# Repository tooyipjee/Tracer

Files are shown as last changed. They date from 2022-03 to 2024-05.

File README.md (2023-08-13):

# Tracer - A Wearable for Things!

 
 The Tracer is an open-source ESP32-based Inertial Measurement Unit tracker that allows you to track the motion and orientation of objects and stream the data to your smartphone or computer.
 
 This repository contains the following content;
 - Schematic
 - Example code to get started with streaming data over Bluetooth (BLE) to your smartphone via [Phyphox](https://github.com/phyphox)
 - 3D Visualisation via Processing
 
 ## What is it
Have you ever wanted to just stick an IMU on a thing to trace its pose and motion?
Tracer provides reliable high-performance and cost efficient tracking of objects for a variety of applications. Tracer can be easily mounted using a high quality velcro strap, allowing it to be fastened on the frame of a bicycle for lean and cadence tracking or even the neck of a tennis racquet to count number of strokes and potentially differentiate between top spin and slice. Let you imagination run wild!

Leveraging on existing open-source projects the Tracer fully supports integration with Phyphox, and can be programmed using Micropython, and Arduino. Power users can also use the [ESP-IDF](https://github.com/espressif/esp-idf) tool for maximum customisation. 

Key Features;
- Leverage the [LSM6DSL](https://www.st.com/en/mems-and-sensors/lsm6dsl.html) to track your objects in real-time.
- Easy mounting using high quality velcro straps that allow the unit to be mounted on a wide variety of objects from your bicycle to track lean angles to an tennis racquet for pose insights.
- On-board Li-ion battery charging using the TP4065.
- Battery Life - 3 hours of continuous streaming over BLE at 10Hz.
- 15m BLE range (unobstructed) - tested on a tennis court

## Use cases

The example code used to test this design involves close integration with the [Madgwick Filter](https://ahrs.readthedocs.io/en/latest/filters/madgwick.html). Using that filter to perform sensor fusion and generate an estimate for heading, roll and pitch, the data can then be relayed to a smartphone or PC for post processing. See below for two example

### Real-time 3D Visualisation
<p align="center">
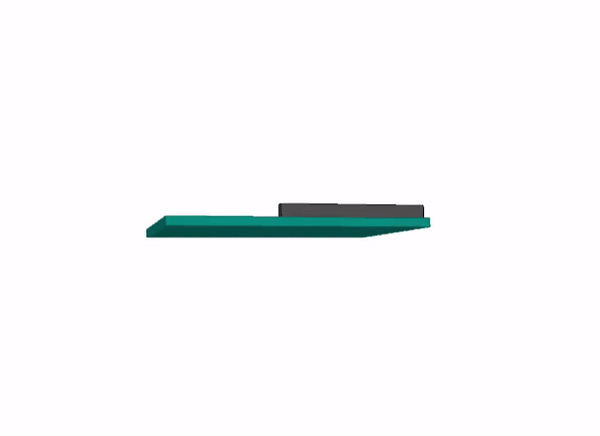
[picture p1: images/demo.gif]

</p>
This 3D visualisation is by streaming data over UART to a simple script that was written on [Processing](https://github.com/processing).

### Stream real-time data to phyphox 
<p align="center">

</p>
The real-time plots from the IMU is streamed over BLE to the phone. Data can later be exported over CSV for further analysis if required. Phyphox is also capable of performing DSP which should offload any energy intensive computation from the ESP32.

## Specification
* Microcontroller | [ESP32-PICO-D4](https://www.espressif.com/en/producttype/esp32-pico-d4)
    * WiFi | 802.11b/g/n
    * Bluetooth | BLE 4.2
    * FLASH | 4MB
    * Programming | USB over UART (CP2104)
* Inertial Measurement Unit (IMU) | [LSM6DSLTR](https://www.st.com/en/mems-and-sensors/lsm6dsl.html)
    * Accelerometer | ±2/±4/±8/±16 g at 1.6 Hz to 6.7KHz
    * Gyroscope | ±125/±250/±500/±1000/±2000 dps at 12.5 Hz to 6.7 KHz
* Time-of-Flight (TOF) | [VL53L0X](https://www.st.com/en/imaging-and-photonics-solutions/vl53l0x.html)
    * Range | Up to 2m
    * 1D Gesture Recognition
* Li-ion Battery Management | TP4065
* Power | 700mA 3.3V LDO
* Mechanical
    * Weight | 20g, including velcro strap
    * Dimensions | 4.2 x 3.6 cm
    * Mounting Options | Velcro Strap or 3x M.2.Screws

## License

MIT License

Copyright (c) 2022 tooyipjee

Permission is hereby granted, free of charge, to any person obtaining a copy
of this software and associated documentation files (the "Software"), to deal
in the Software without restriction, including without limitation the rights
to use, copy, modify, merge, publish, distribute, sublicense, and/or sell
copies of the Software, and to permit persons to whom the Software is
furnished to do so, subject to the following conditions:

The above copyright notice and this permission notice shall be included in all
copies or substantial portions of the Software.

THE SOFTWARE IS PROVIDED "AS IS", WITHOUT WARRANTY OF ANY KIND, EXPRESS OR
IMPLIED, INCLUDING BUT NOT LIMITED TO THE WARRANTIES OF MERCHANTABILITY,
FITNESS FOR A PARTICULAR PURPOSE AND NONINFRINGEMENT. IN NO EVENT SHALL THE
AUTHORS OR COPYRIGHT HOLDERS BE LIABLE FOR ANY CLAIM, DAMAGES OR OTHER
LIABILITY, WHETHER IN AN ACTION OF CONTRACT, TORT OR OTHERWISE, ARISING FROM,
OUT OF OR IN CONNECTION WITH THE SOFTWARE OR THE USE OR OTHER DEALINGS IN THE
SOFTWARE.

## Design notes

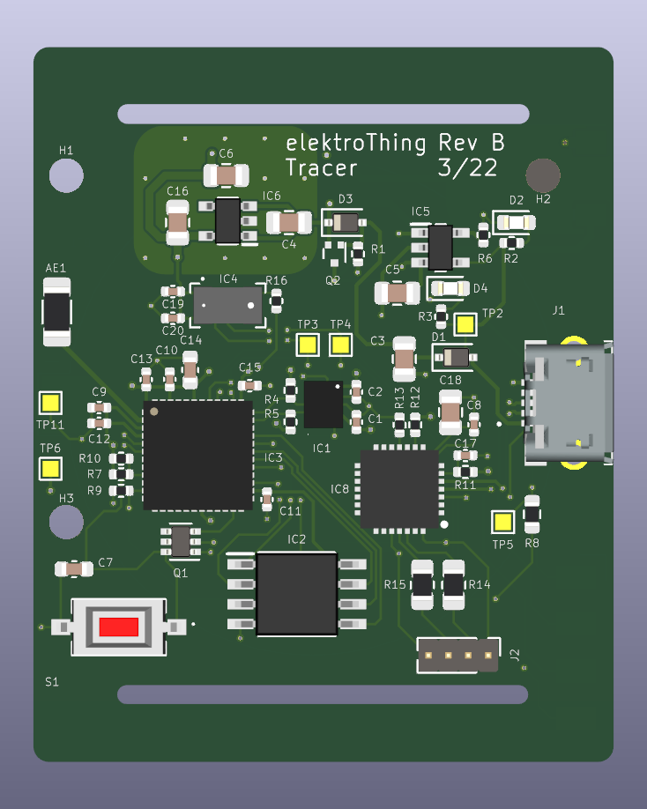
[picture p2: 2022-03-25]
images/pinout/hardware.png

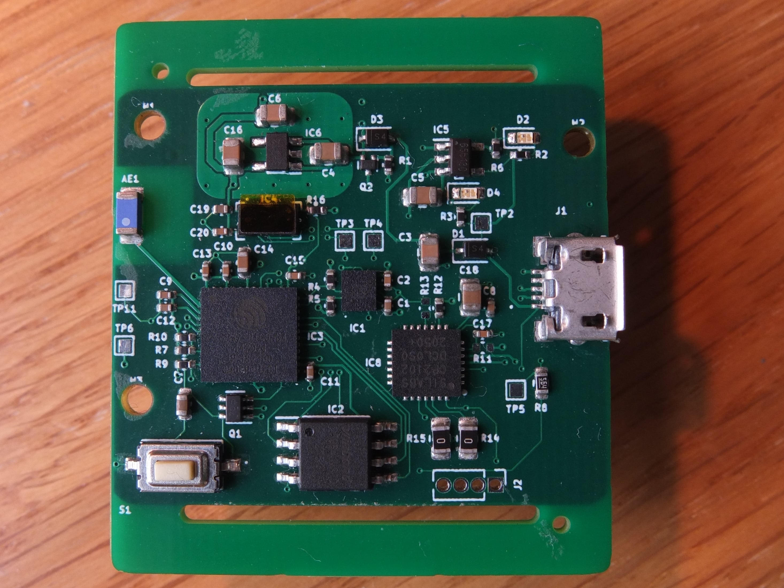
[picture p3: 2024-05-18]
images/revB/DSCF9603-min.JPG

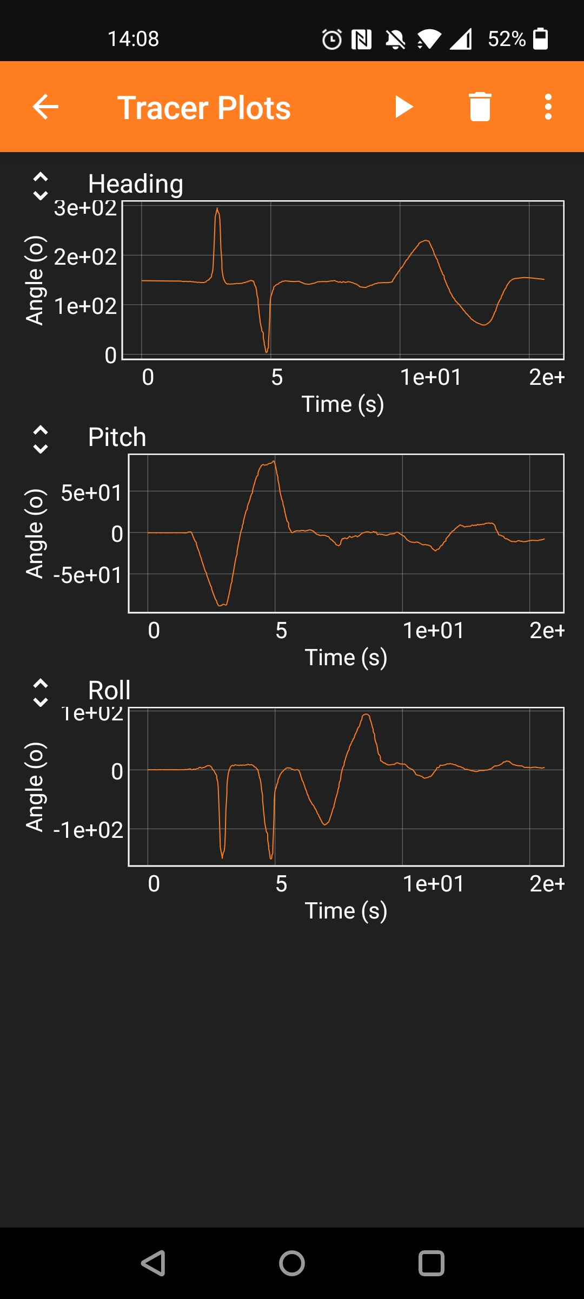
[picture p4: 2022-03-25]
images/phyphox.jpg

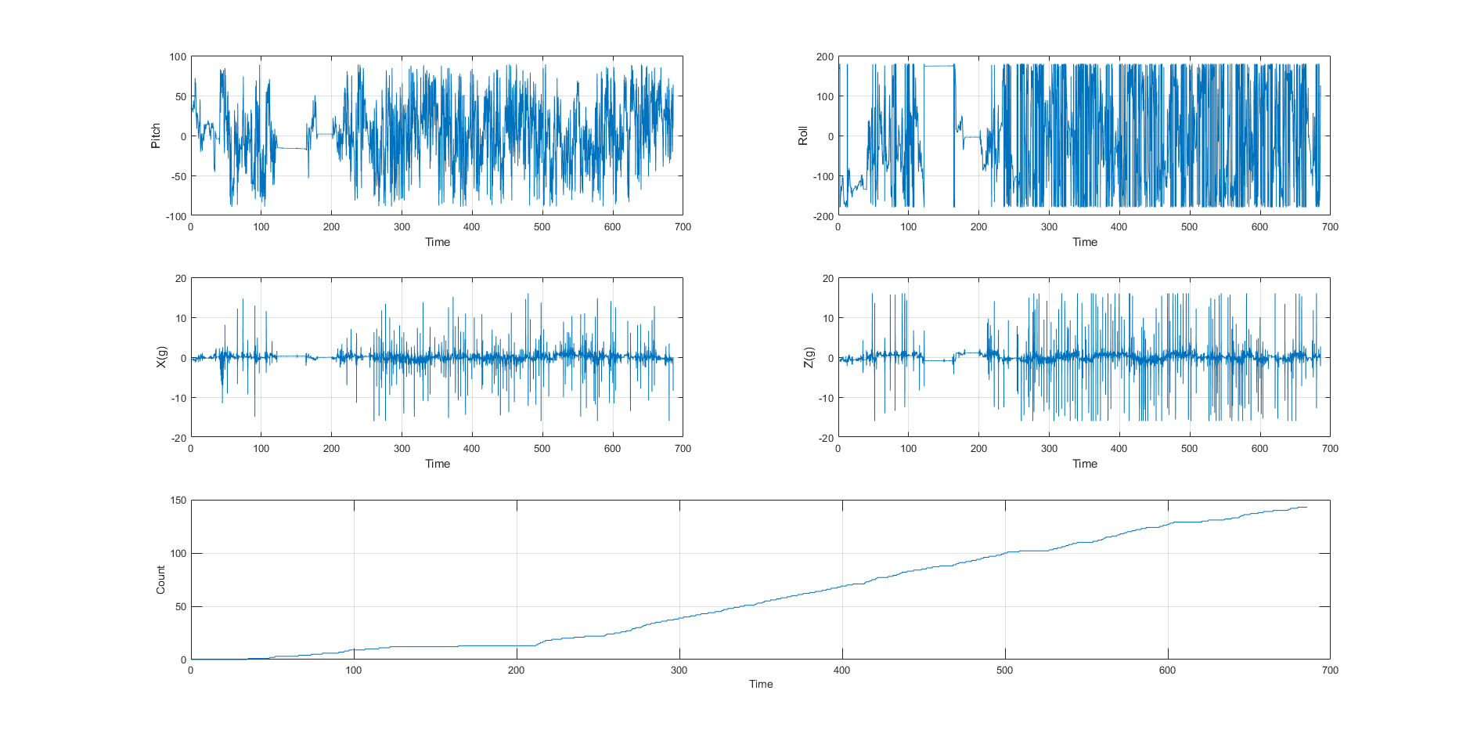
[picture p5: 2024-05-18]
images/tennis_18-4.png

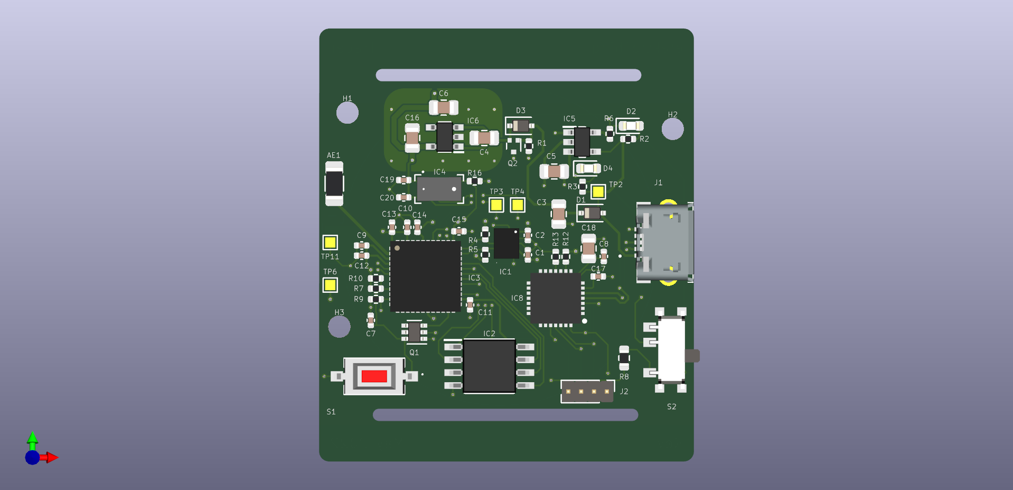
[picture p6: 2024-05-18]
images/Tracer.png

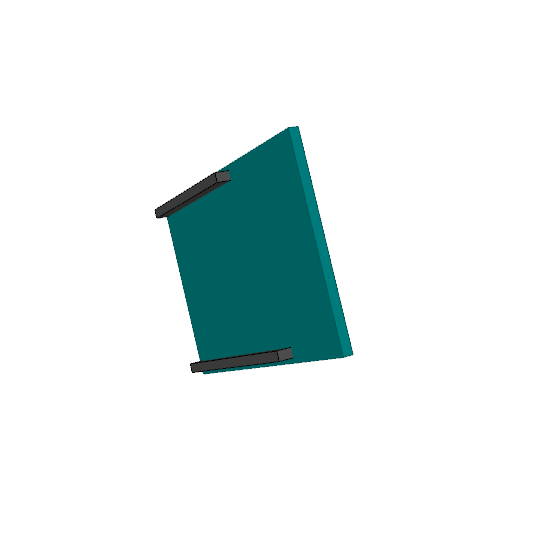
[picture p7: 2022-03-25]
images/visual.png

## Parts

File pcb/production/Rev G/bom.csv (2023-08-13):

Designator | Footprint | Quantity | Value | LCSC Part #
BT1 | BS-24-B4AK014 | 1 | CR2450 | C964813
C1, C7 | 0402 | 2 | 1u | C52923
C10 | 1206 | 1 | 4.7u | C29823
C11, C12, C13, C14, C2, C5, C6 | 0402 | 7 | 100n | C307331
C15 | 0402 | 1 | 10u_0402 | C315248
C3, C4, C8, C9 | 0805 | 4 | 10u | C15850
D2, D3, D4, D5 | 0603 | 4 | Green_0603 | C72043
D6 | B5819WSL | 1 | B5819W.SL | C8598
H1, H2, H3 | MountingHole_2.2mm_M2_Small | 3 | MountingHole
IC1 | ESP32C3MINI1N4 | 1 | ESP32-C3-MINI-1-N4 | C2838502
IC2 | SOT95P280X130-5N | 1 | XC6227C331MR-G | C216640
IC3 | QFN50P300X300X100-17N-D | 1 | BQ24073RGTR | C15220
IC4 | LSM6DSLTR | 1 | LSM6DSLTR | C126672
IC5 | QFN50P500X500X80-29N-D | 1 | CP2102N-A02-GQFN28R | C6568
J1 | GT-USB-7010A | 1 | GT-USB-7010 | C963370
J2 | SHDRRA2W50P0X200_1X2_600X760X510P | 1 | PH-2RA | C225207
JP1, JP2 | SolderJumper-3_P1.3mm_Bridged12_Pad1.0x1.5mm_NumberLabels | 2 | SolderJumper_3_Bridged12
Q1 | SOT-363_SC-70-6 | 1 | MUN5214DW1T1G | C94403
R1, R18, R19, R3 | 0402 | 4 | 10k | C25744
R10, R11, R2 | 0402 | 3 | 2.2k | C25879
R12, R13, R14, R15, R5 | 0402 | 5 | 51k | C25794
R16 | 0603 | 1 | 560k | C23203
R17 | 0402 | 1 | 220k | C25767
R20, R4 | 0402 | 2 | 1k | C11702
R7, R9 | 0402 | 2 | 1.5k | C25867
R8 | 0402 | 1 | 100k | C25741
S1, S2 | TS1101CW | 2 | TS-1101-C-W | C318938
S3 | K31296SE1 | 1 | K3-1296S-E1 | C128955
TH1 | 0402 | 1 | 10k_NTC | C333993
TP11 | TestPoint_Pad_1.0x1.0mm | 1 | TestPoint_Alt

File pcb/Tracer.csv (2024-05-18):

Comment | Designator | Footprint | LCSC
CR2450 | BT1 | BatteryHolders:BS-24-B4AK014 | C964813
1u | C1,C7 | Capacitor_SMD:C_0402_1005Metric | C52923
4.7u | C10 | Capacitor_SMD:C_1206_3216Metric | C29823
10u_0402 | C15 | Capacitor_SMD:C_0402_1005Metric | C315248
100n | C2,C5,C6,C11,C12,C13,C14 | Capacitor_SMD:C_0402_1005Metric | C307331
10u | C3,C4,C8,C9 | Capacitor_SMD:C_0805_2012Metric | C15850
SD103AWS | D1 | Diode_SMD:D_SOD-323 | C181207
Green_0603 | D2,D3,D4,D5 | LED_SMD:LED_0603_1608Metric | C72043
MountingHole | H1,H2,H3 | personal:MountingHole_2.2mm_M2_Small
ESP32-C3-MINI-1-N4 | IC1 | ESP32C3MINI1N4 | C2838502
XC6227C331MR-G | IC2 | SOT95P280X130-5N | C216640
BQ24073RGTR | IC3 | QFN50P300X300X100-17N-D | C15220
LSM6DSLTR | IC4 | LSM6DSLTR | C126672
CP2102N-A02-GQFN28R | IC5 | QFN50P500X500X80-29N-D | C6568
GT-USB-7010 | J1 | Connectors_JT:GT-USB-7010A | C963370
MUN5214DW1T1G | Q1 | Package_TO_SOT_SMD:SOT-363_SC-70-6 | C94403
10k | R1,R3,R12,R13,R14,R15,R18,R19 | Resistor_SMD:R_0402_1005Metric | C25744
560k | R16 | Resistor_SMD:R_0603_1608Metric | C23203
220k | R17 | Resistor_SMD:R_0402_1005Metric | C25767
2.2k | R2,R10,R11 | Resistor_SMD:R_0402_1005Metric | C25879
1k | R4,R20 | Resistor_SMD:R_0402_1005Metric | C11702
47.5k | R5 | Resistor_SMD:R_0402_1005Metric | C227098
0 | R6 | Resistor_SMD:R_0805_2012Metric_Pad1.20x1.40mm_HandSolder | C17477
1.5k | R7,R9 | Resistor_SMD:R_0402_1005Metric | C25867
100k | R8 | Resistor_SMD:R_0402_1005Metric | C25741
TS-1101-C-W | S1,S2 | TS1101CW | C318938
K3-1296S-E1 | S3 | K31296SE1 | C128955
10k_NTC | TH1 | Resistor_SMD:R_0402_1005Metric | C333993
TestPoint_Alt | TP11 | TestPoint:TestPoint_Pad_1.0x1.0mm

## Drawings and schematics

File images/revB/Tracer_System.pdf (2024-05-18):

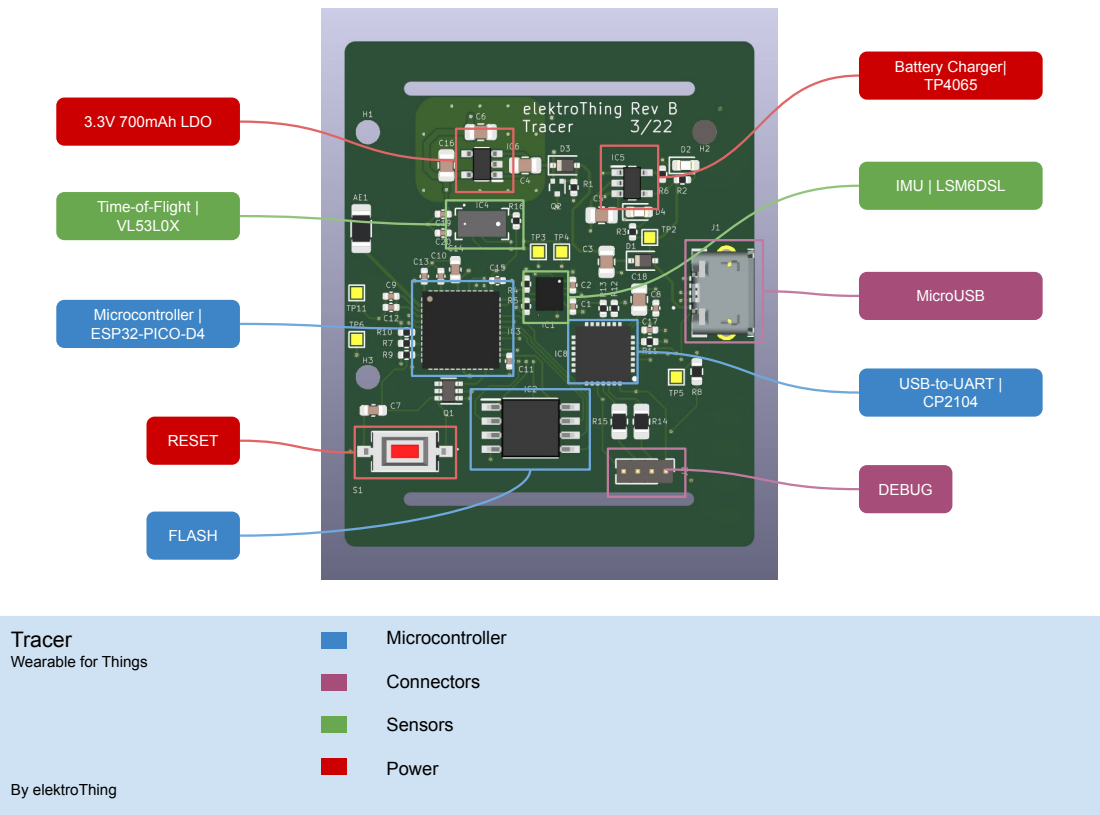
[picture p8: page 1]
By elektroThing; Microcontroller; Connectors; Sensors; Power; 3.3V 700mAh LDO; Microcontroller | ESP32-PICO-D4; RESET; IMU | LSM6DSL; MicroUSB; Battery Charger| TP4065; DEBUG; FLASH

Time-of-Flight

USB-to-UART

Tracer
Wearable for Things

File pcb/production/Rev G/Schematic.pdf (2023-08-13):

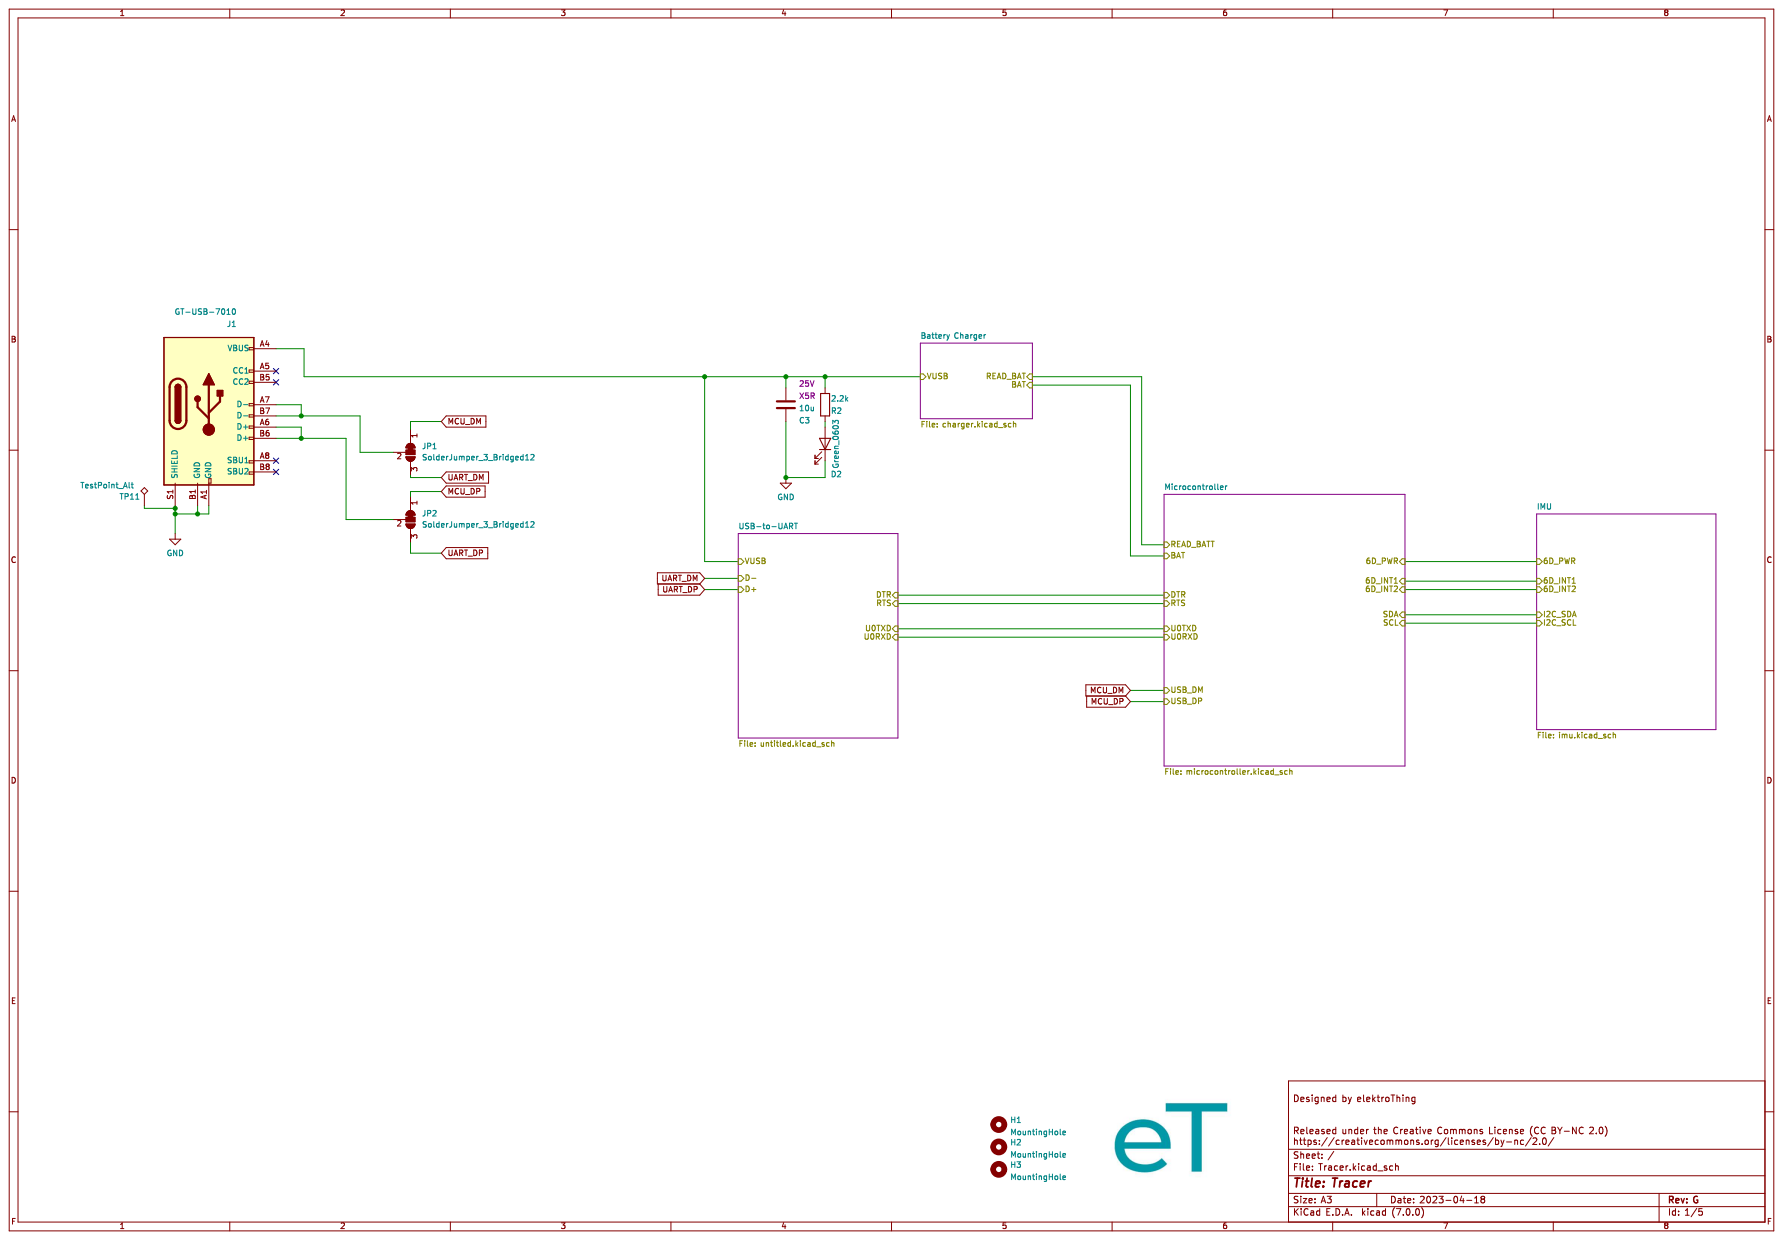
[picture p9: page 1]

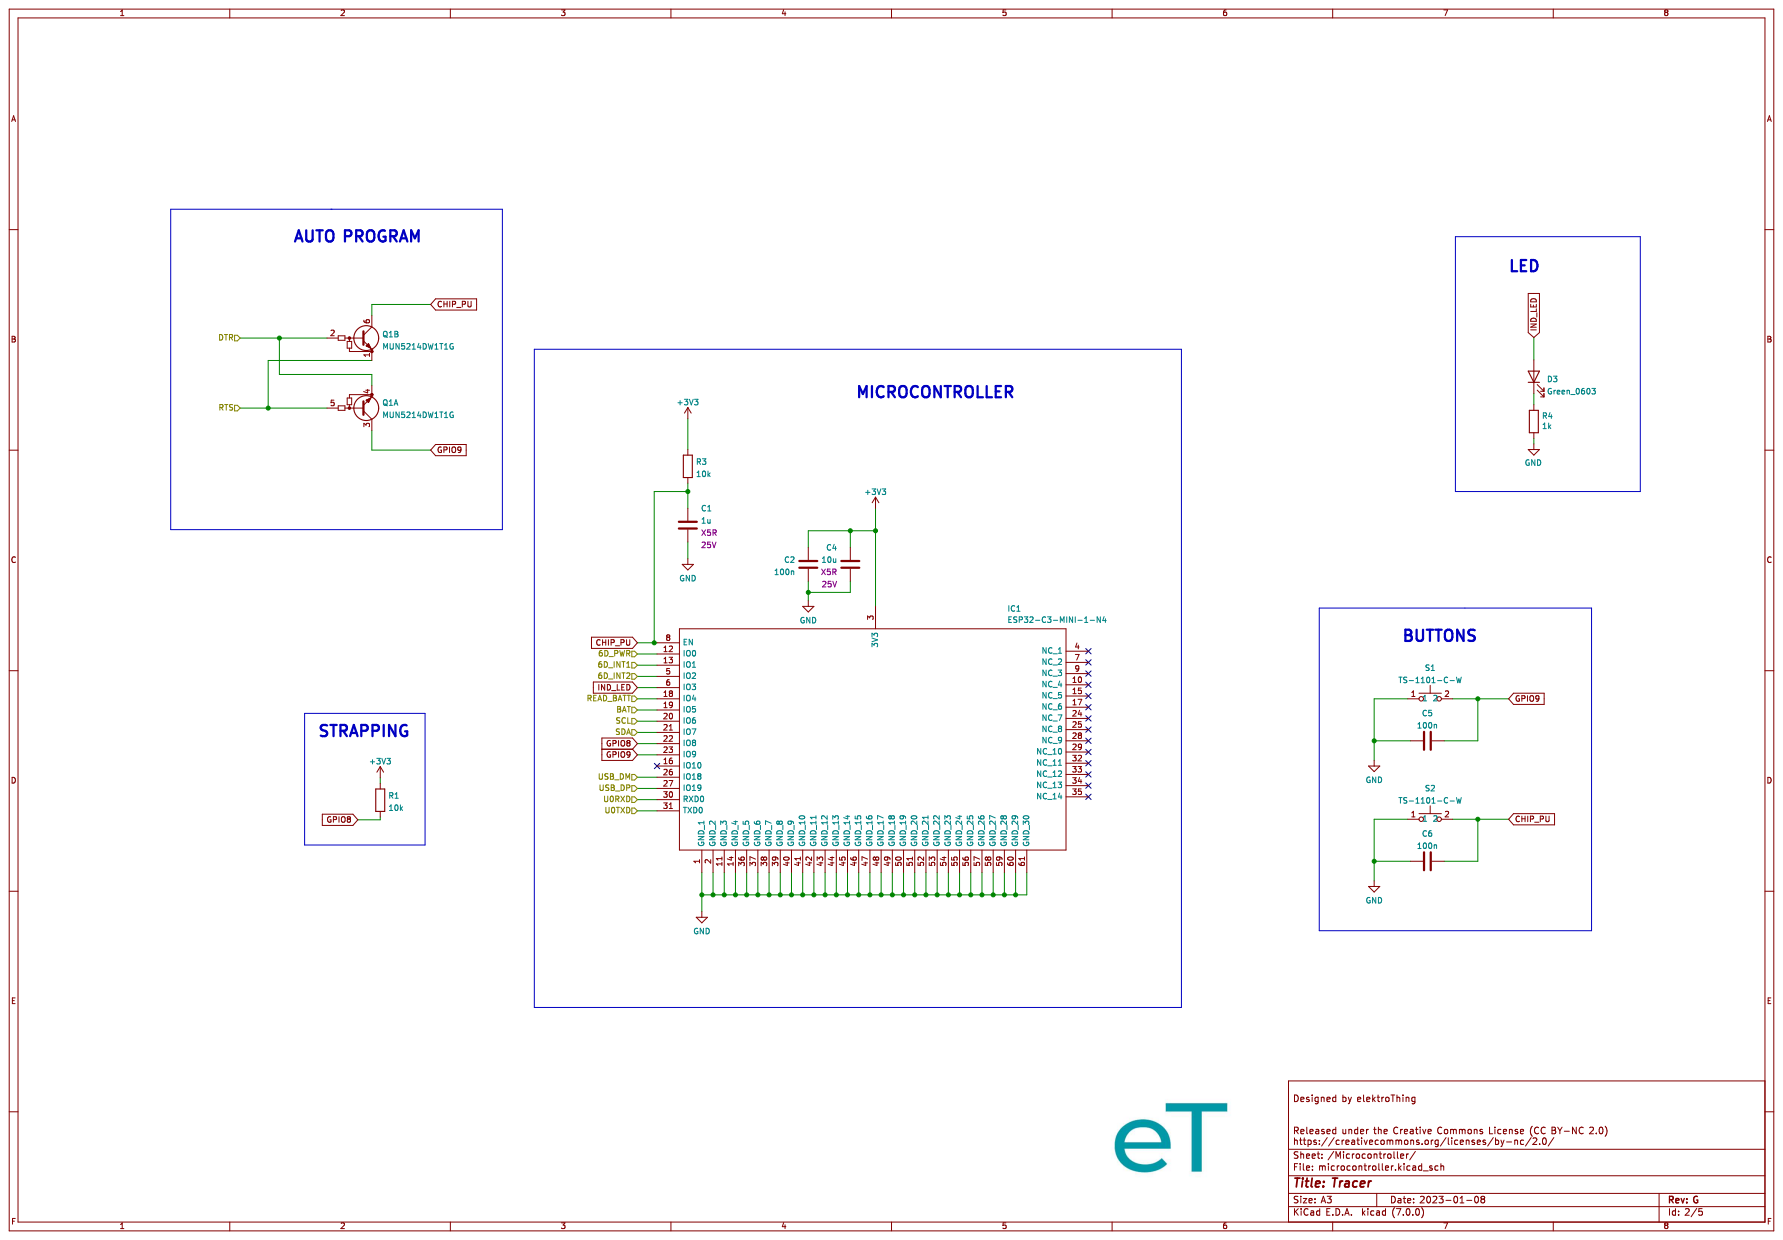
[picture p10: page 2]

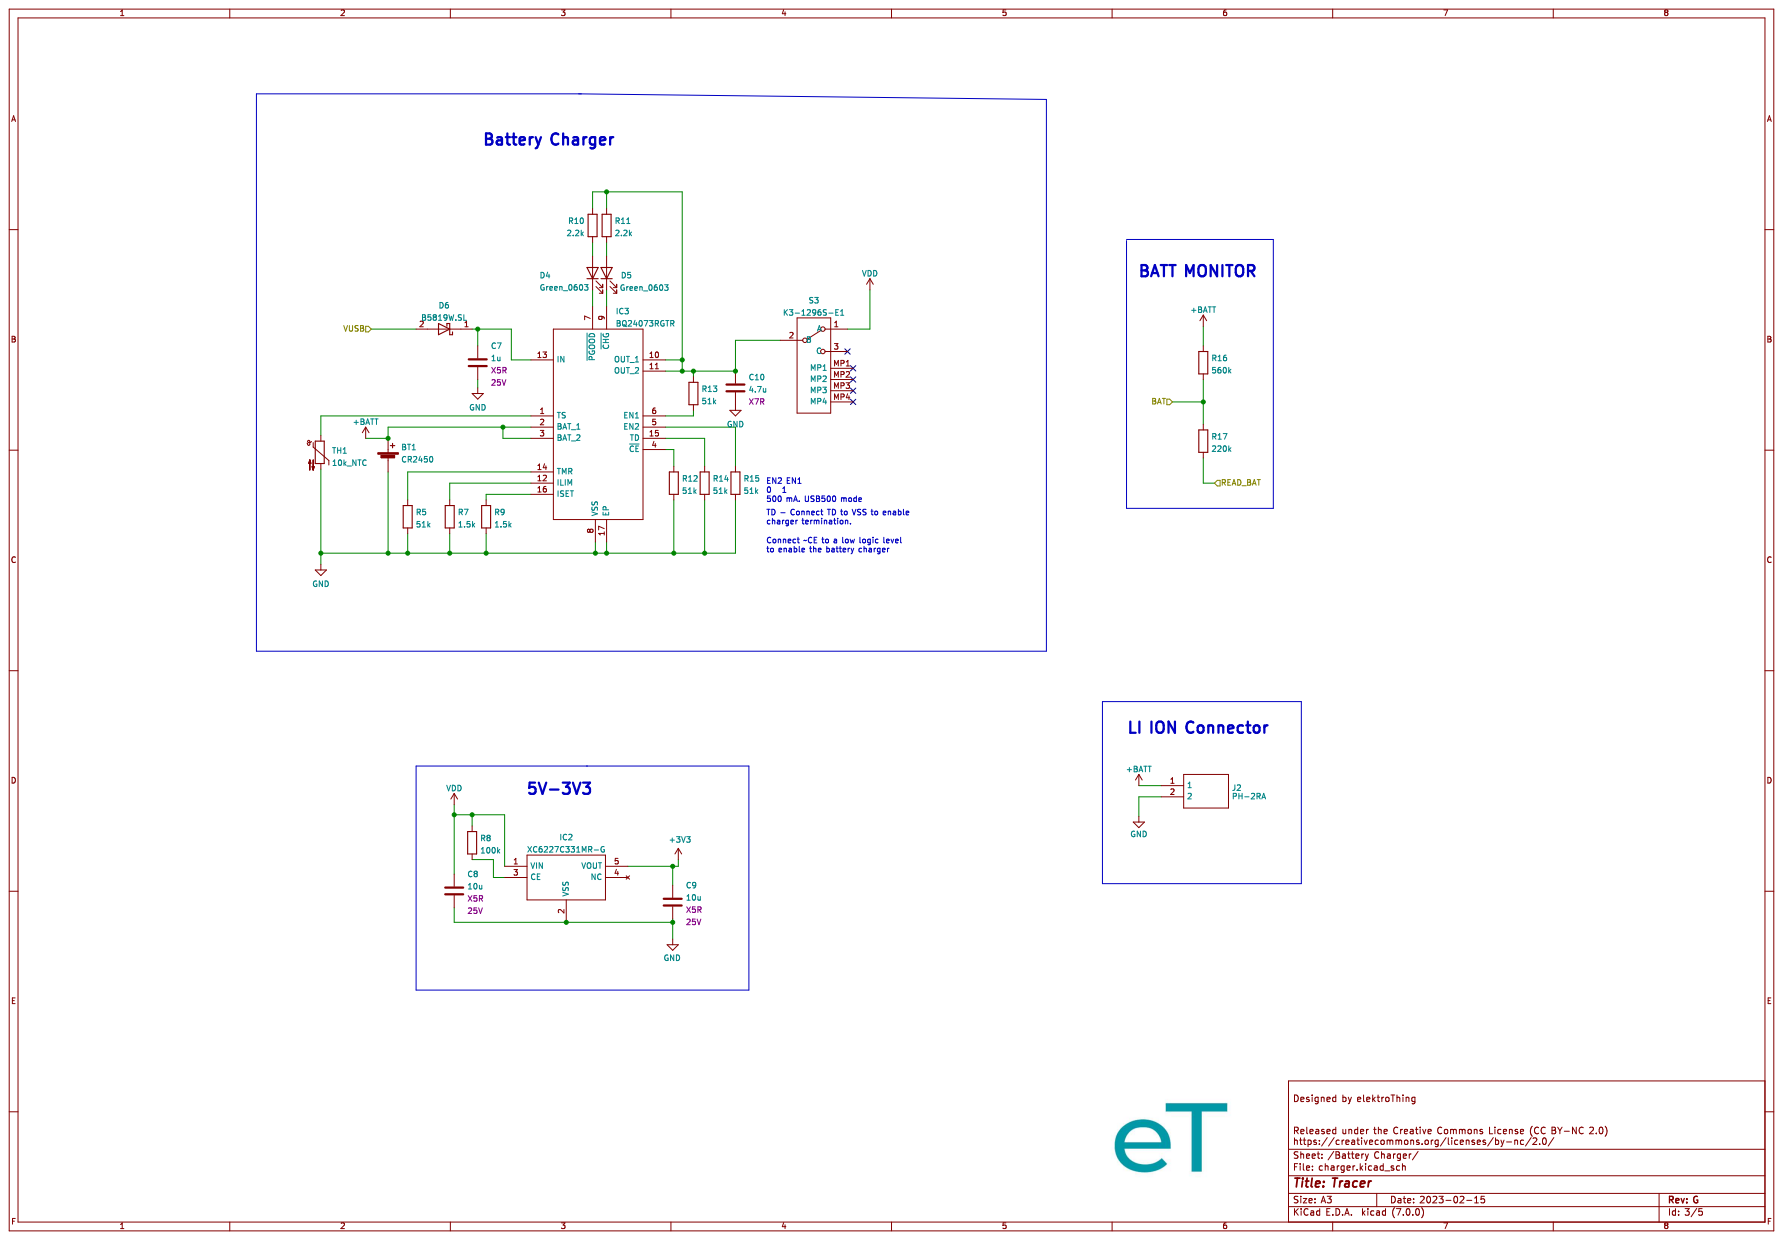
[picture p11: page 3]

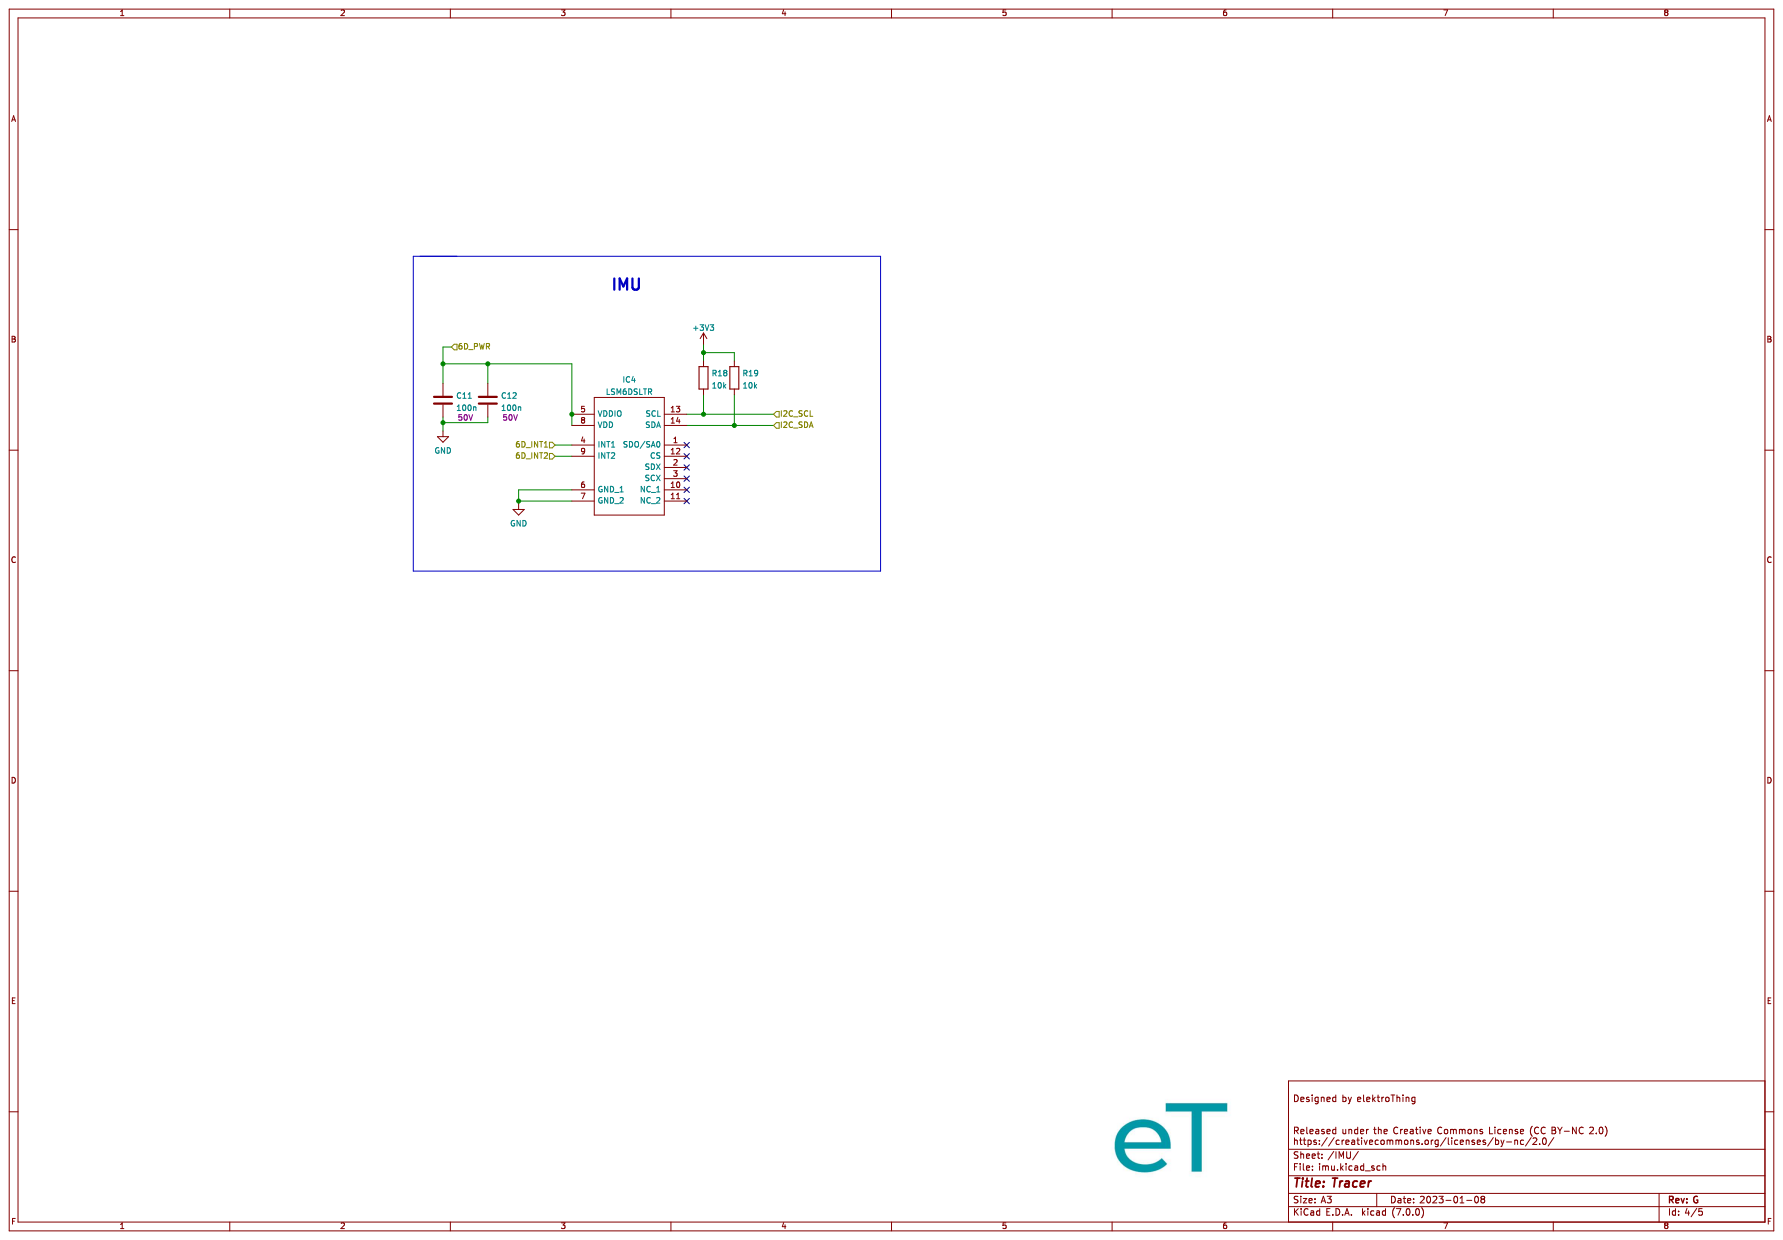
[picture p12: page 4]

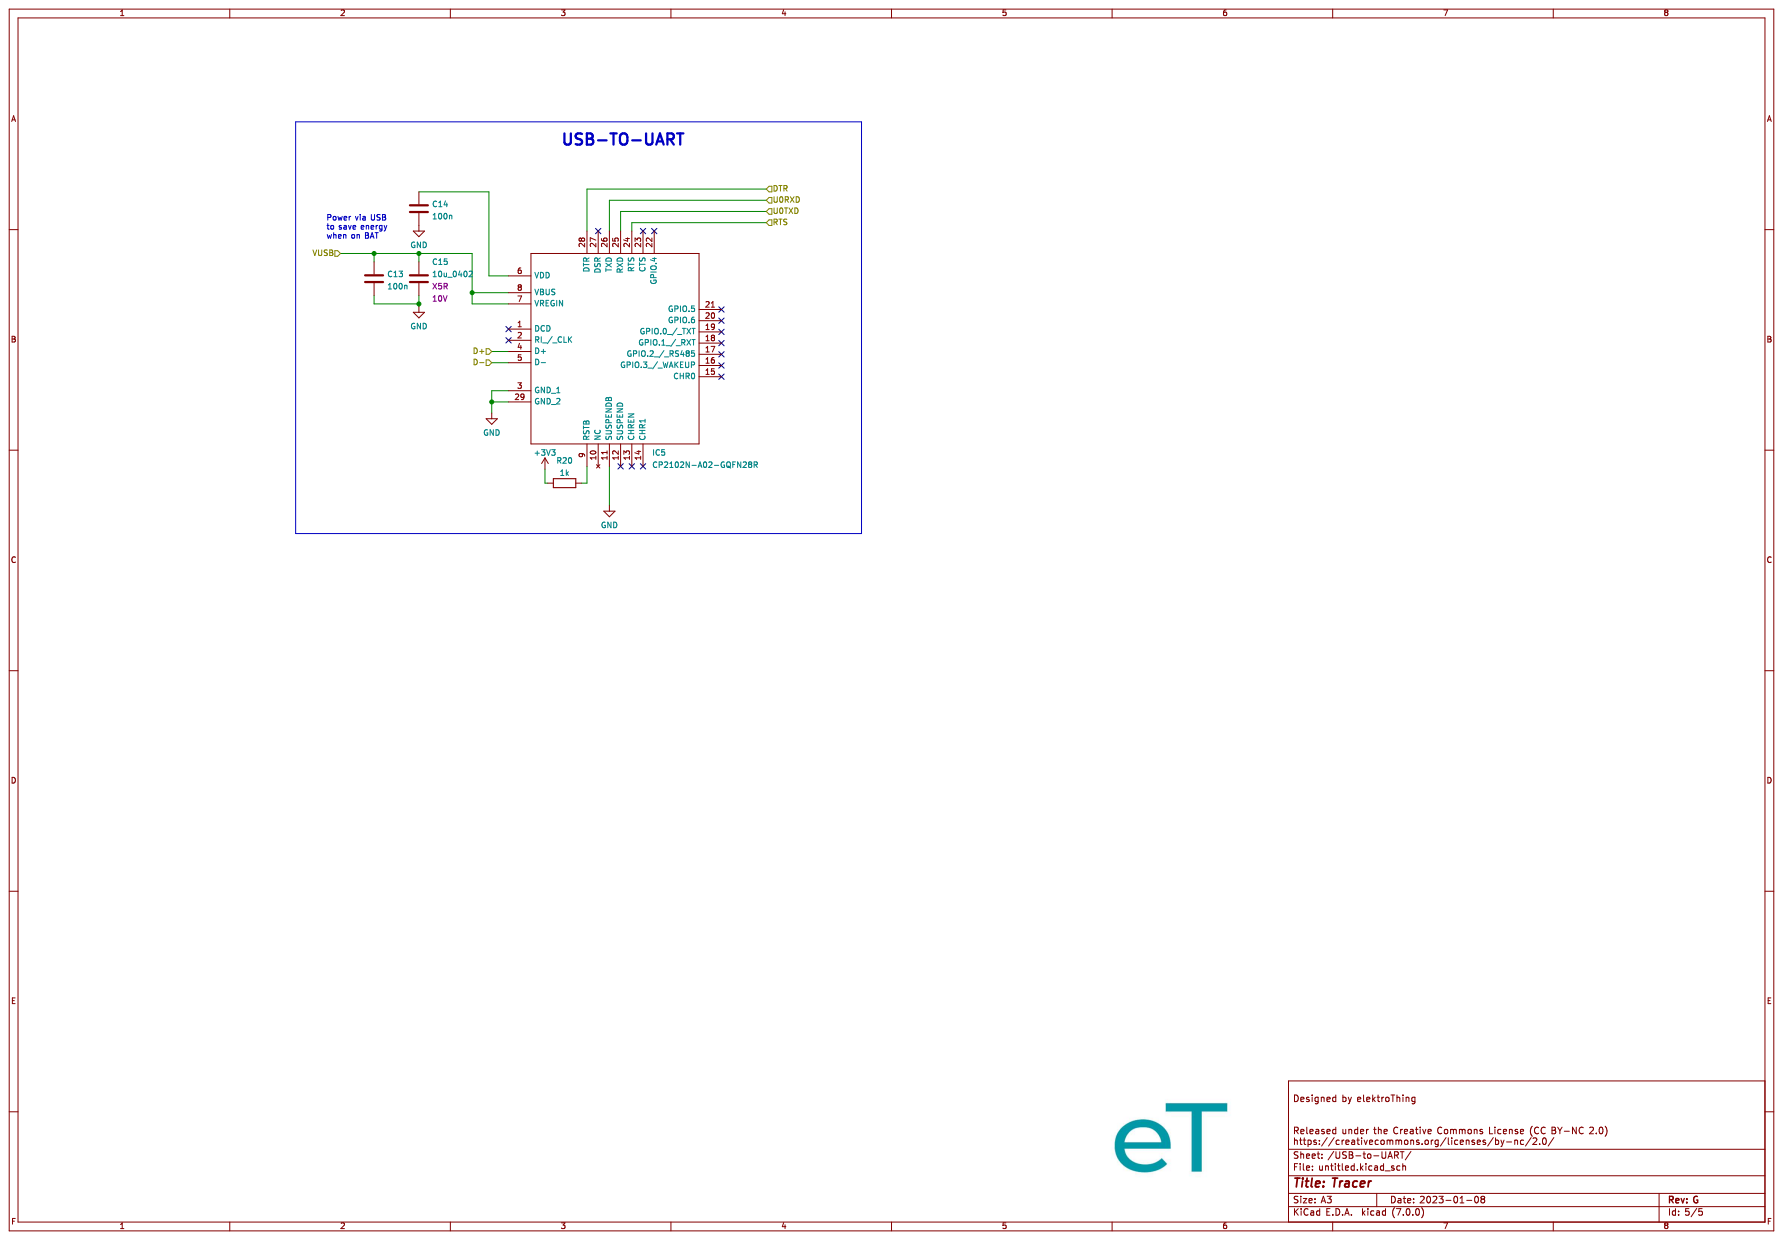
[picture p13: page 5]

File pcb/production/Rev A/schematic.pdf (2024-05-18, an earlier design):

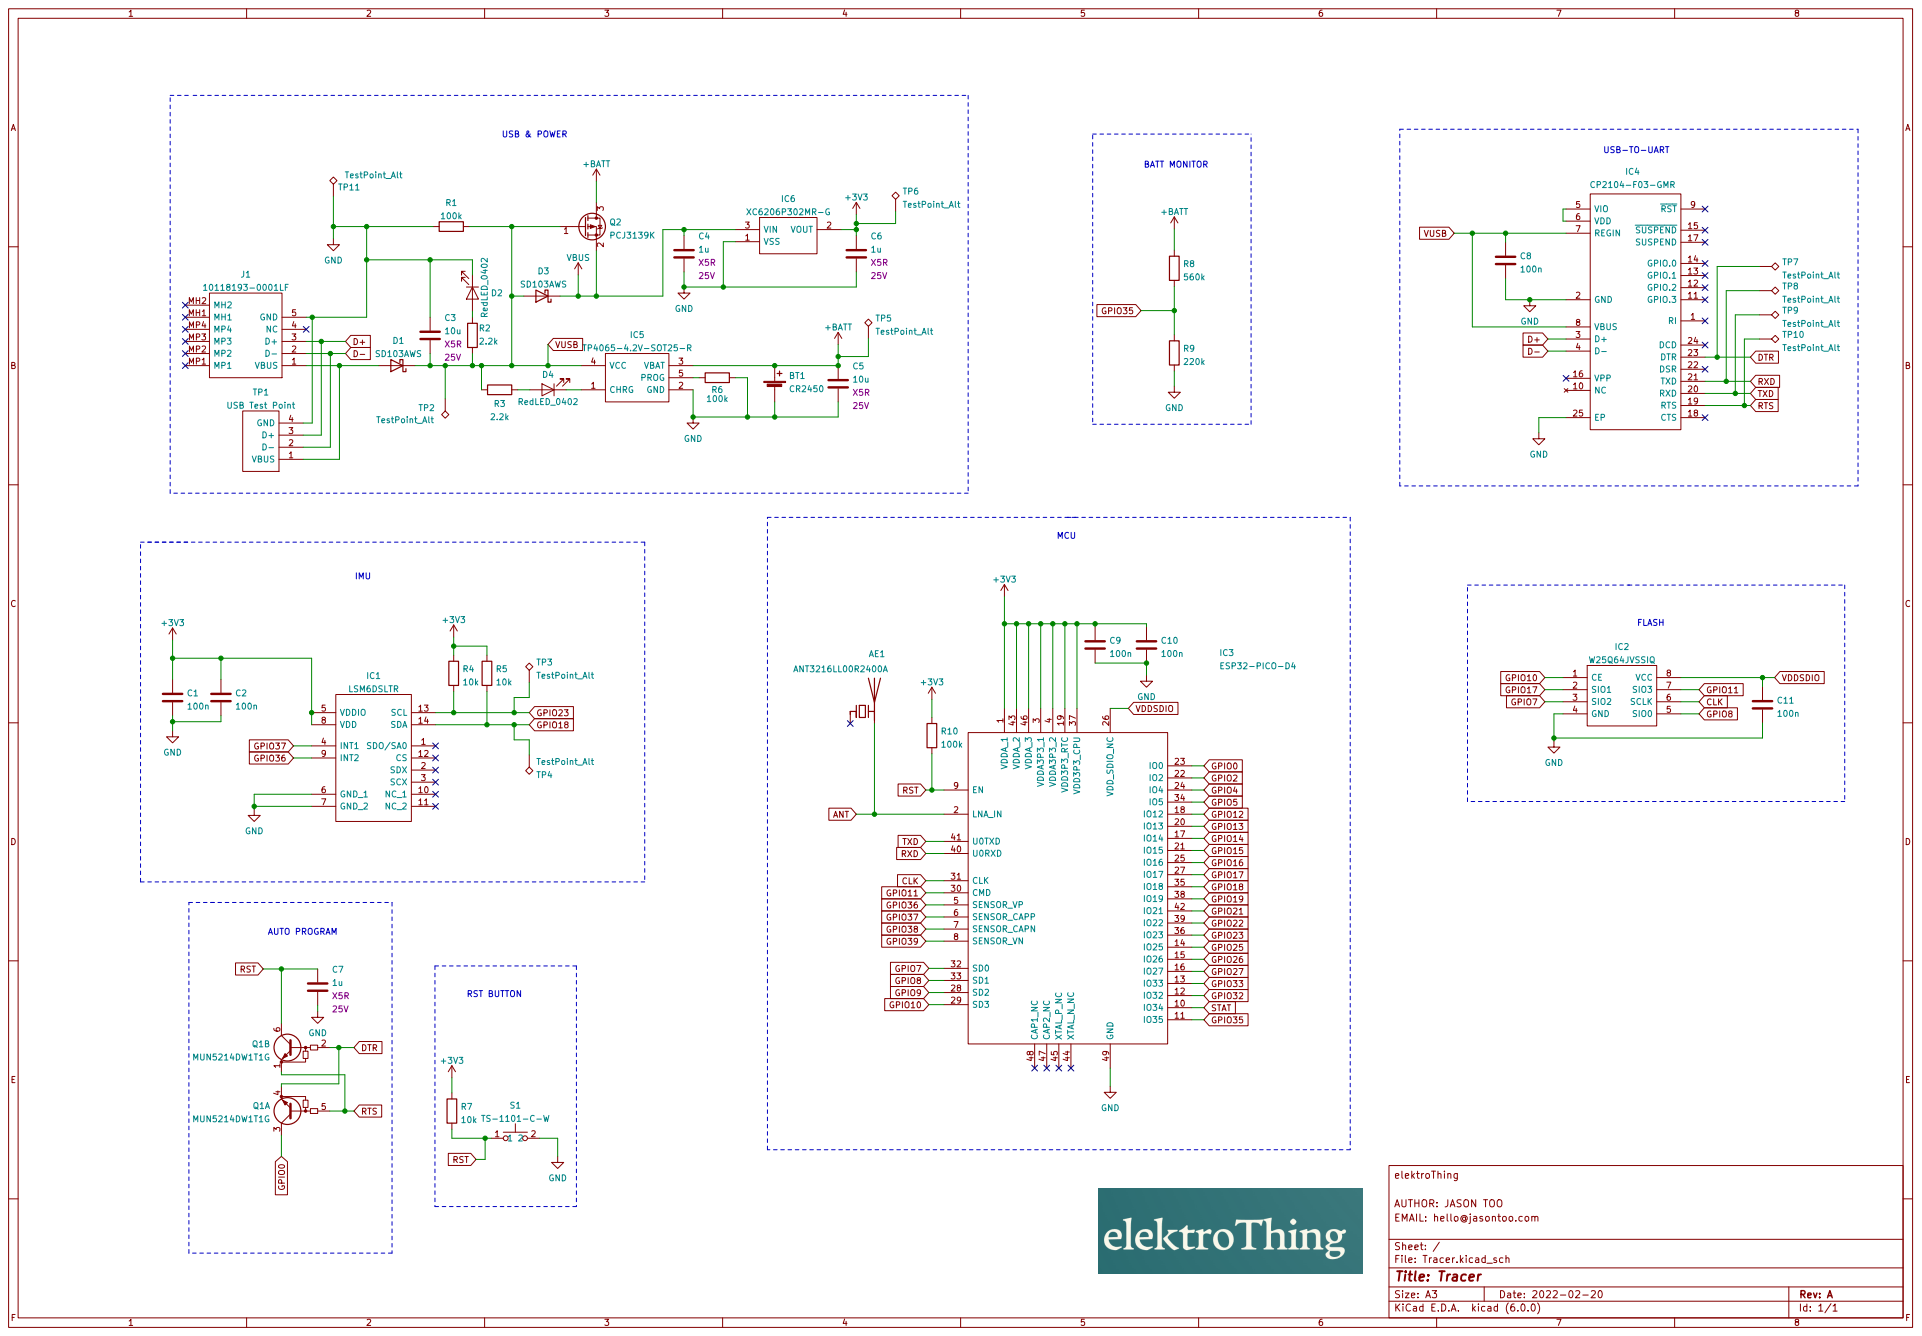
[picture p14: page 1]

USB-TO-UART MCU

AUTHOR: JASON TOO
File: Tracer.kicad_sch Sheet: / EMAIL: hello@jasontoo.com

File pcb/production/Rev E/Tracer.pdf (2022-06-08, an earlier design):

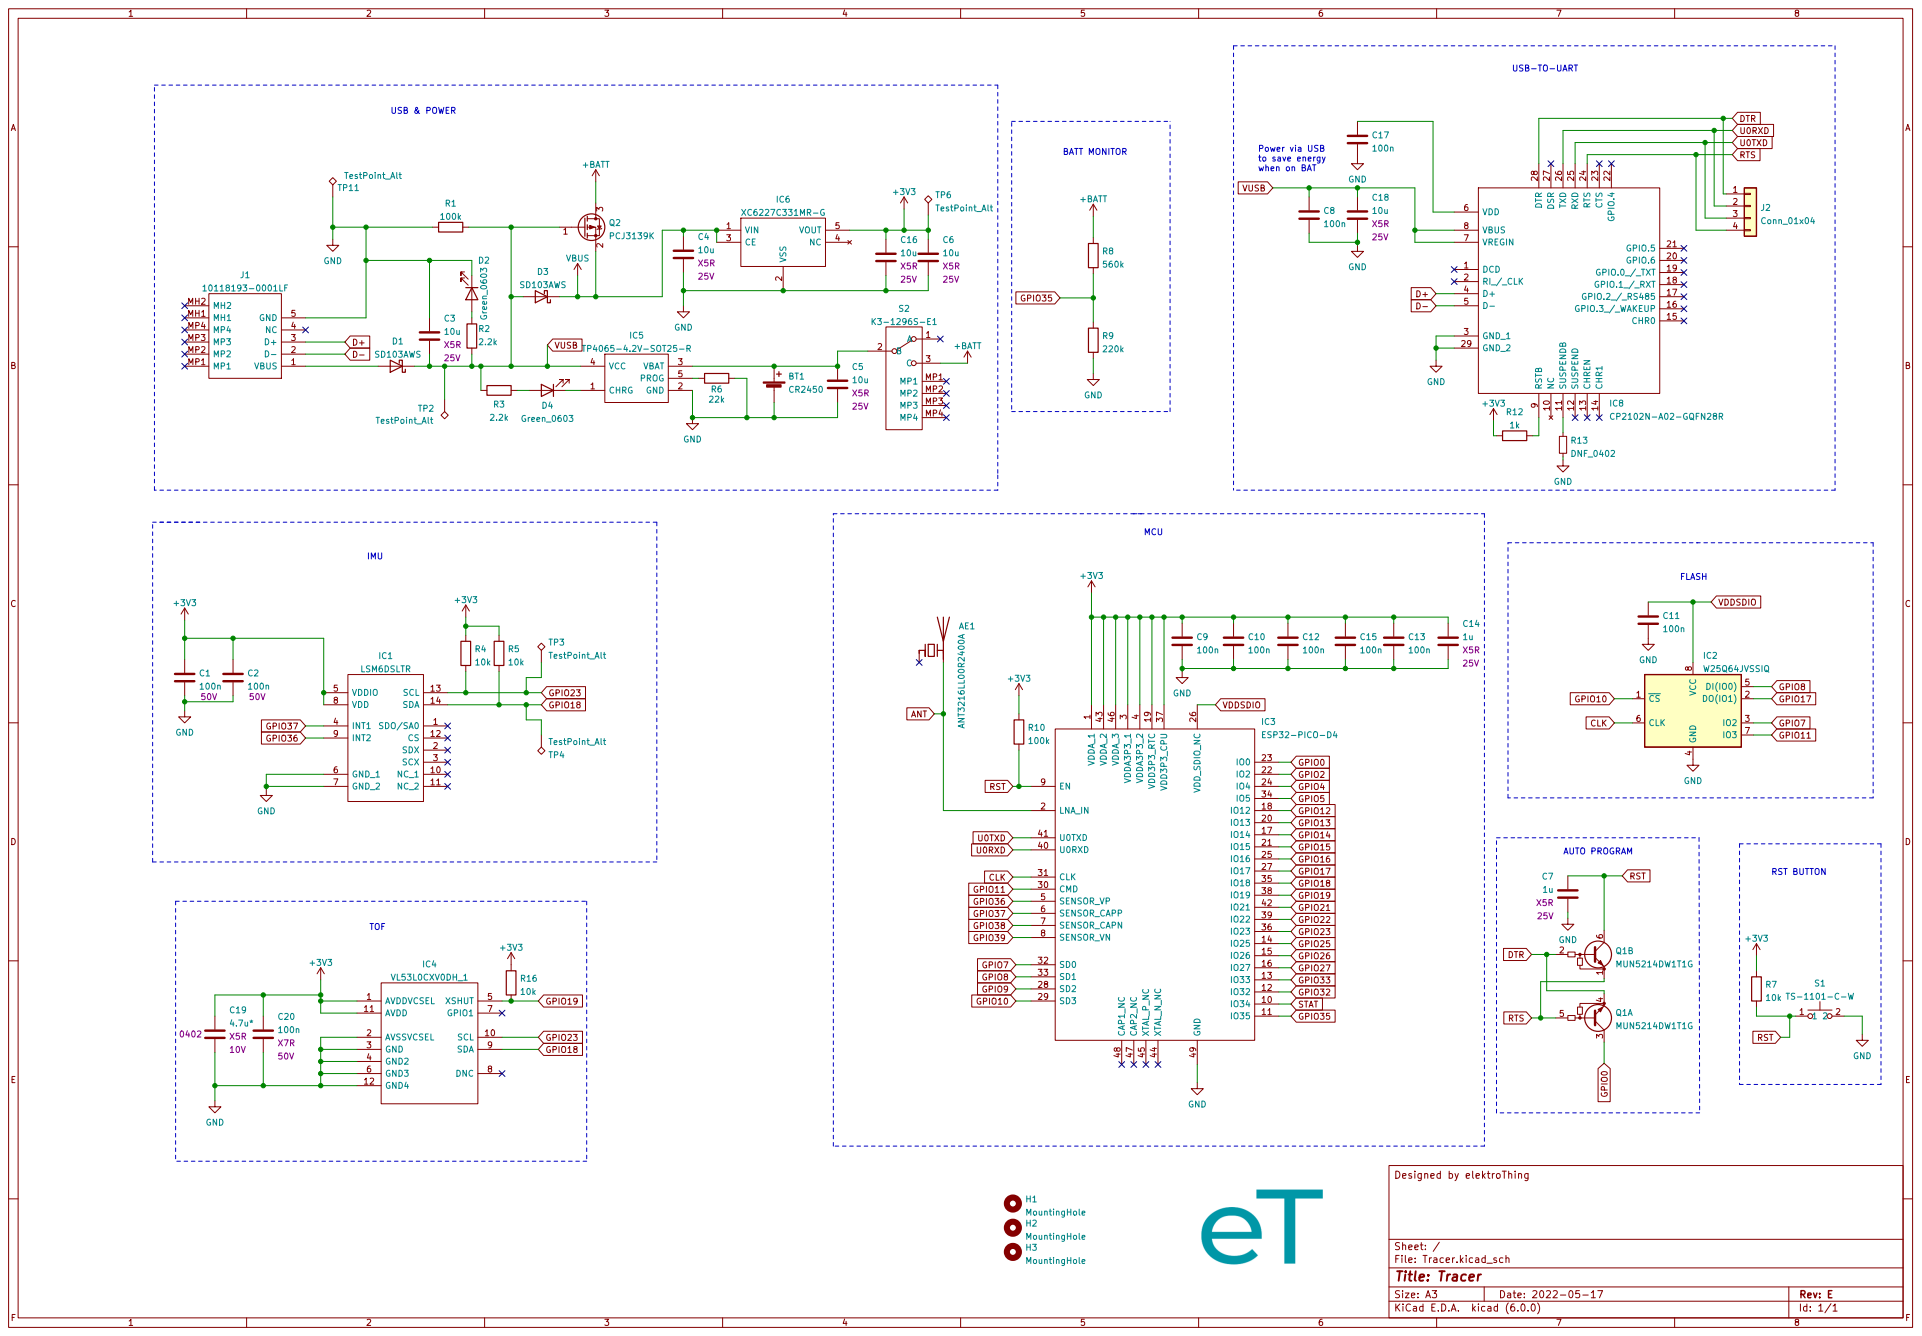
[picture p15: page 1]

Power via USB
to save energy when on BAT

File: Tracer.kicad_sch Sheet: / Designed by elektroThing

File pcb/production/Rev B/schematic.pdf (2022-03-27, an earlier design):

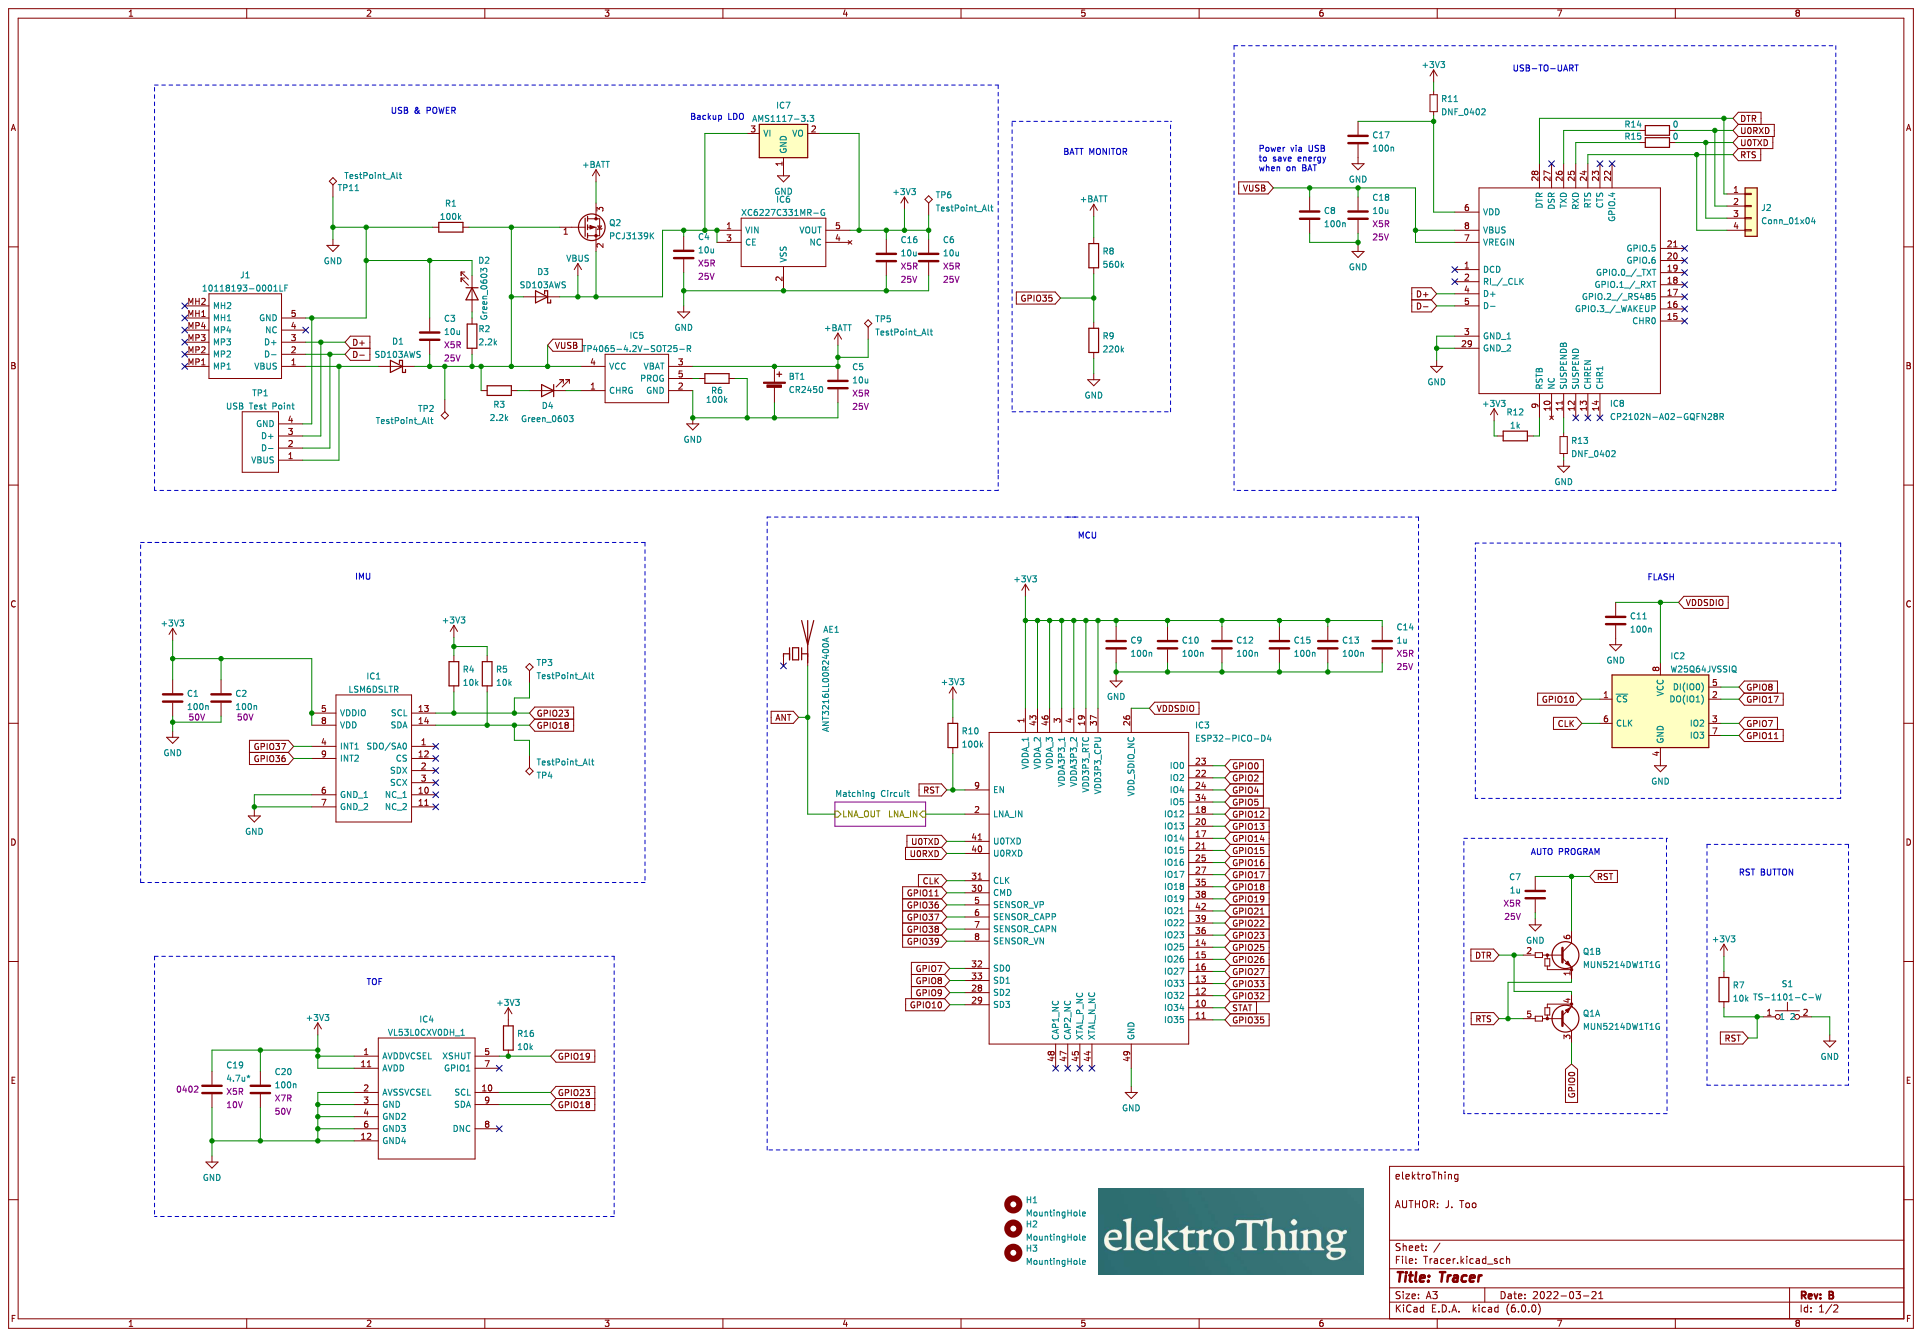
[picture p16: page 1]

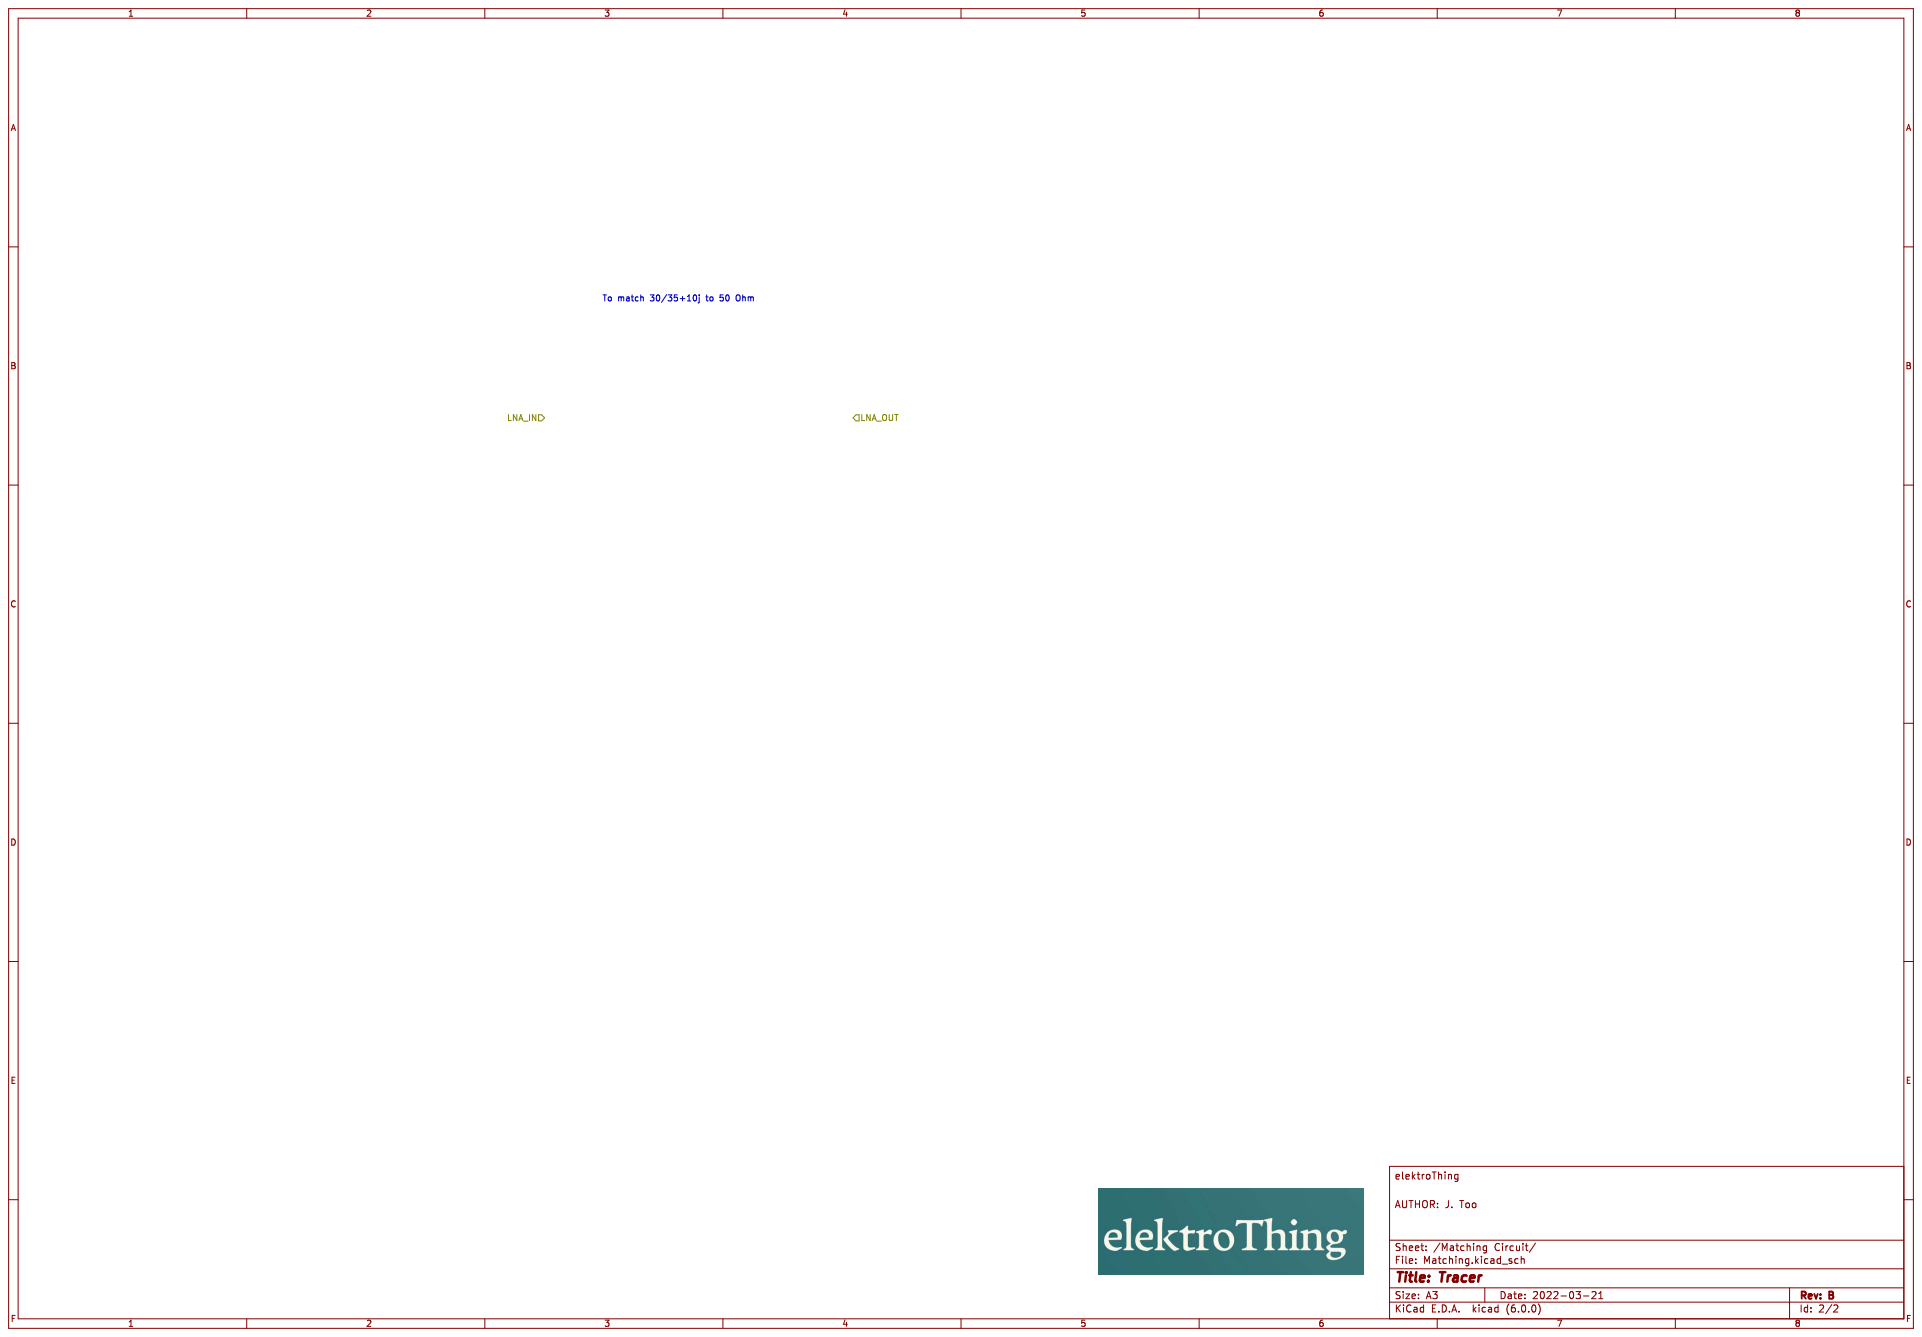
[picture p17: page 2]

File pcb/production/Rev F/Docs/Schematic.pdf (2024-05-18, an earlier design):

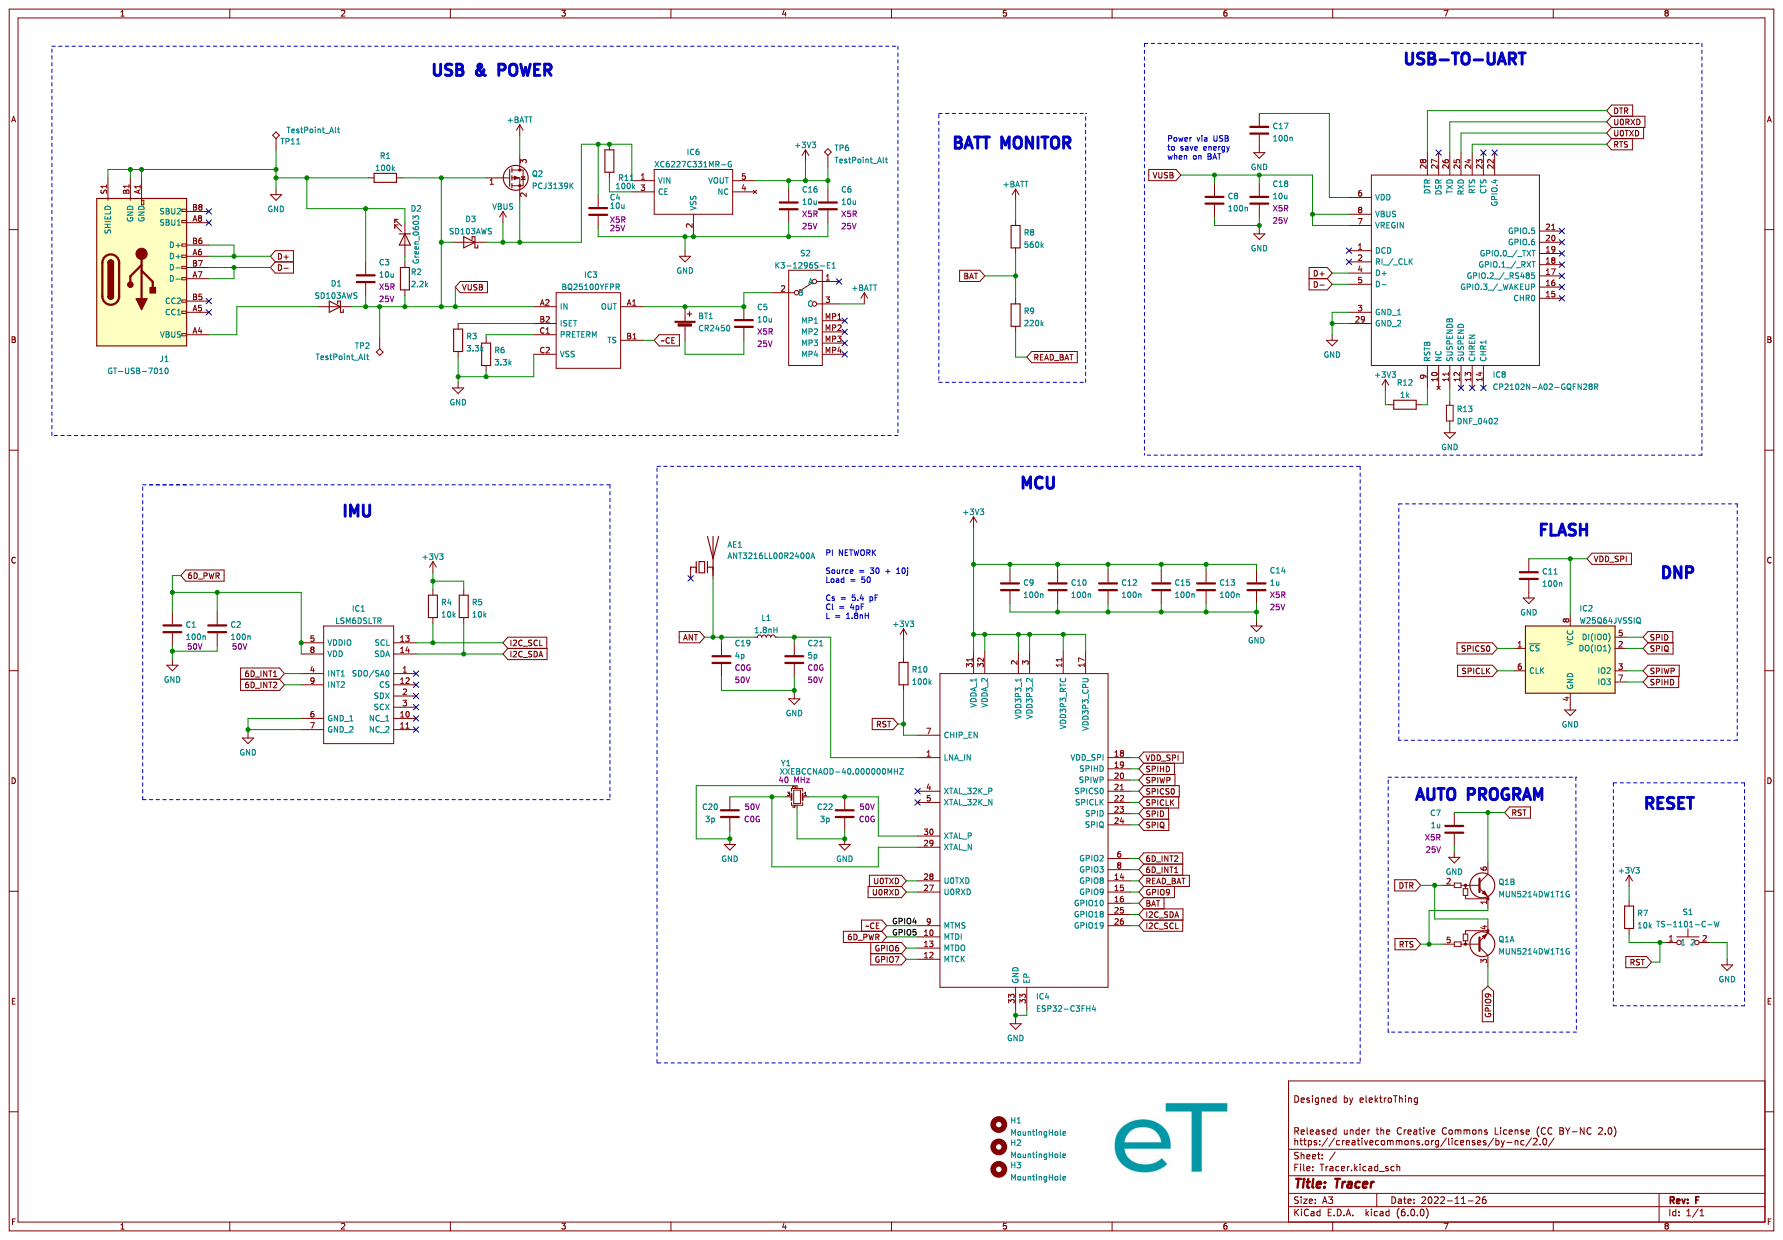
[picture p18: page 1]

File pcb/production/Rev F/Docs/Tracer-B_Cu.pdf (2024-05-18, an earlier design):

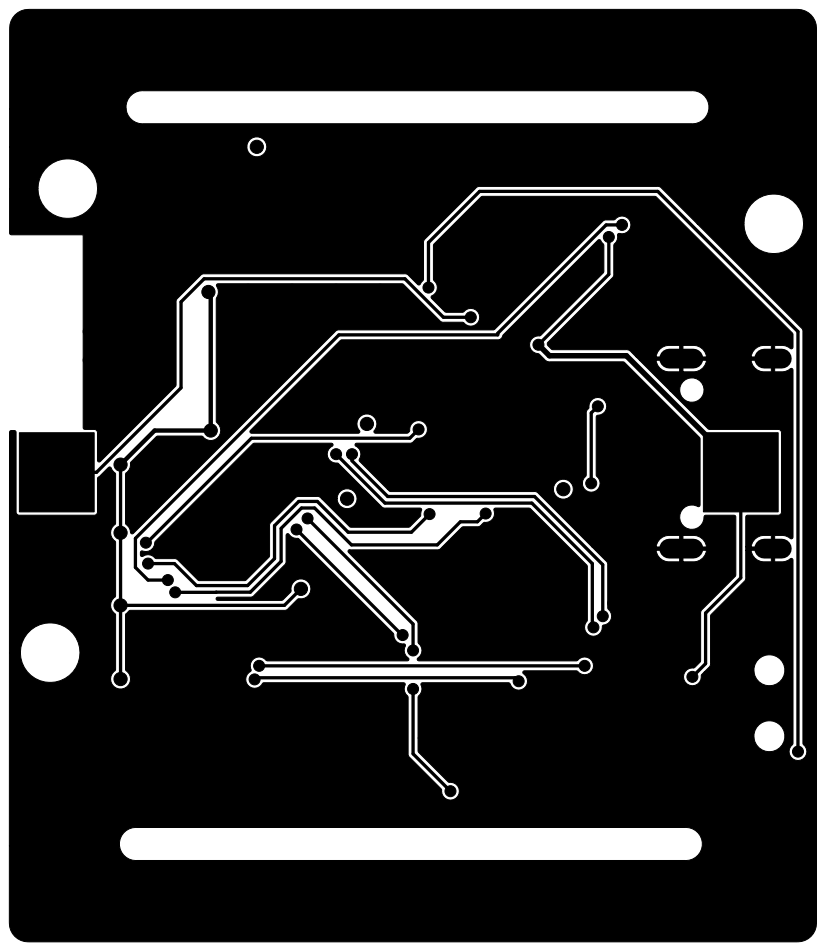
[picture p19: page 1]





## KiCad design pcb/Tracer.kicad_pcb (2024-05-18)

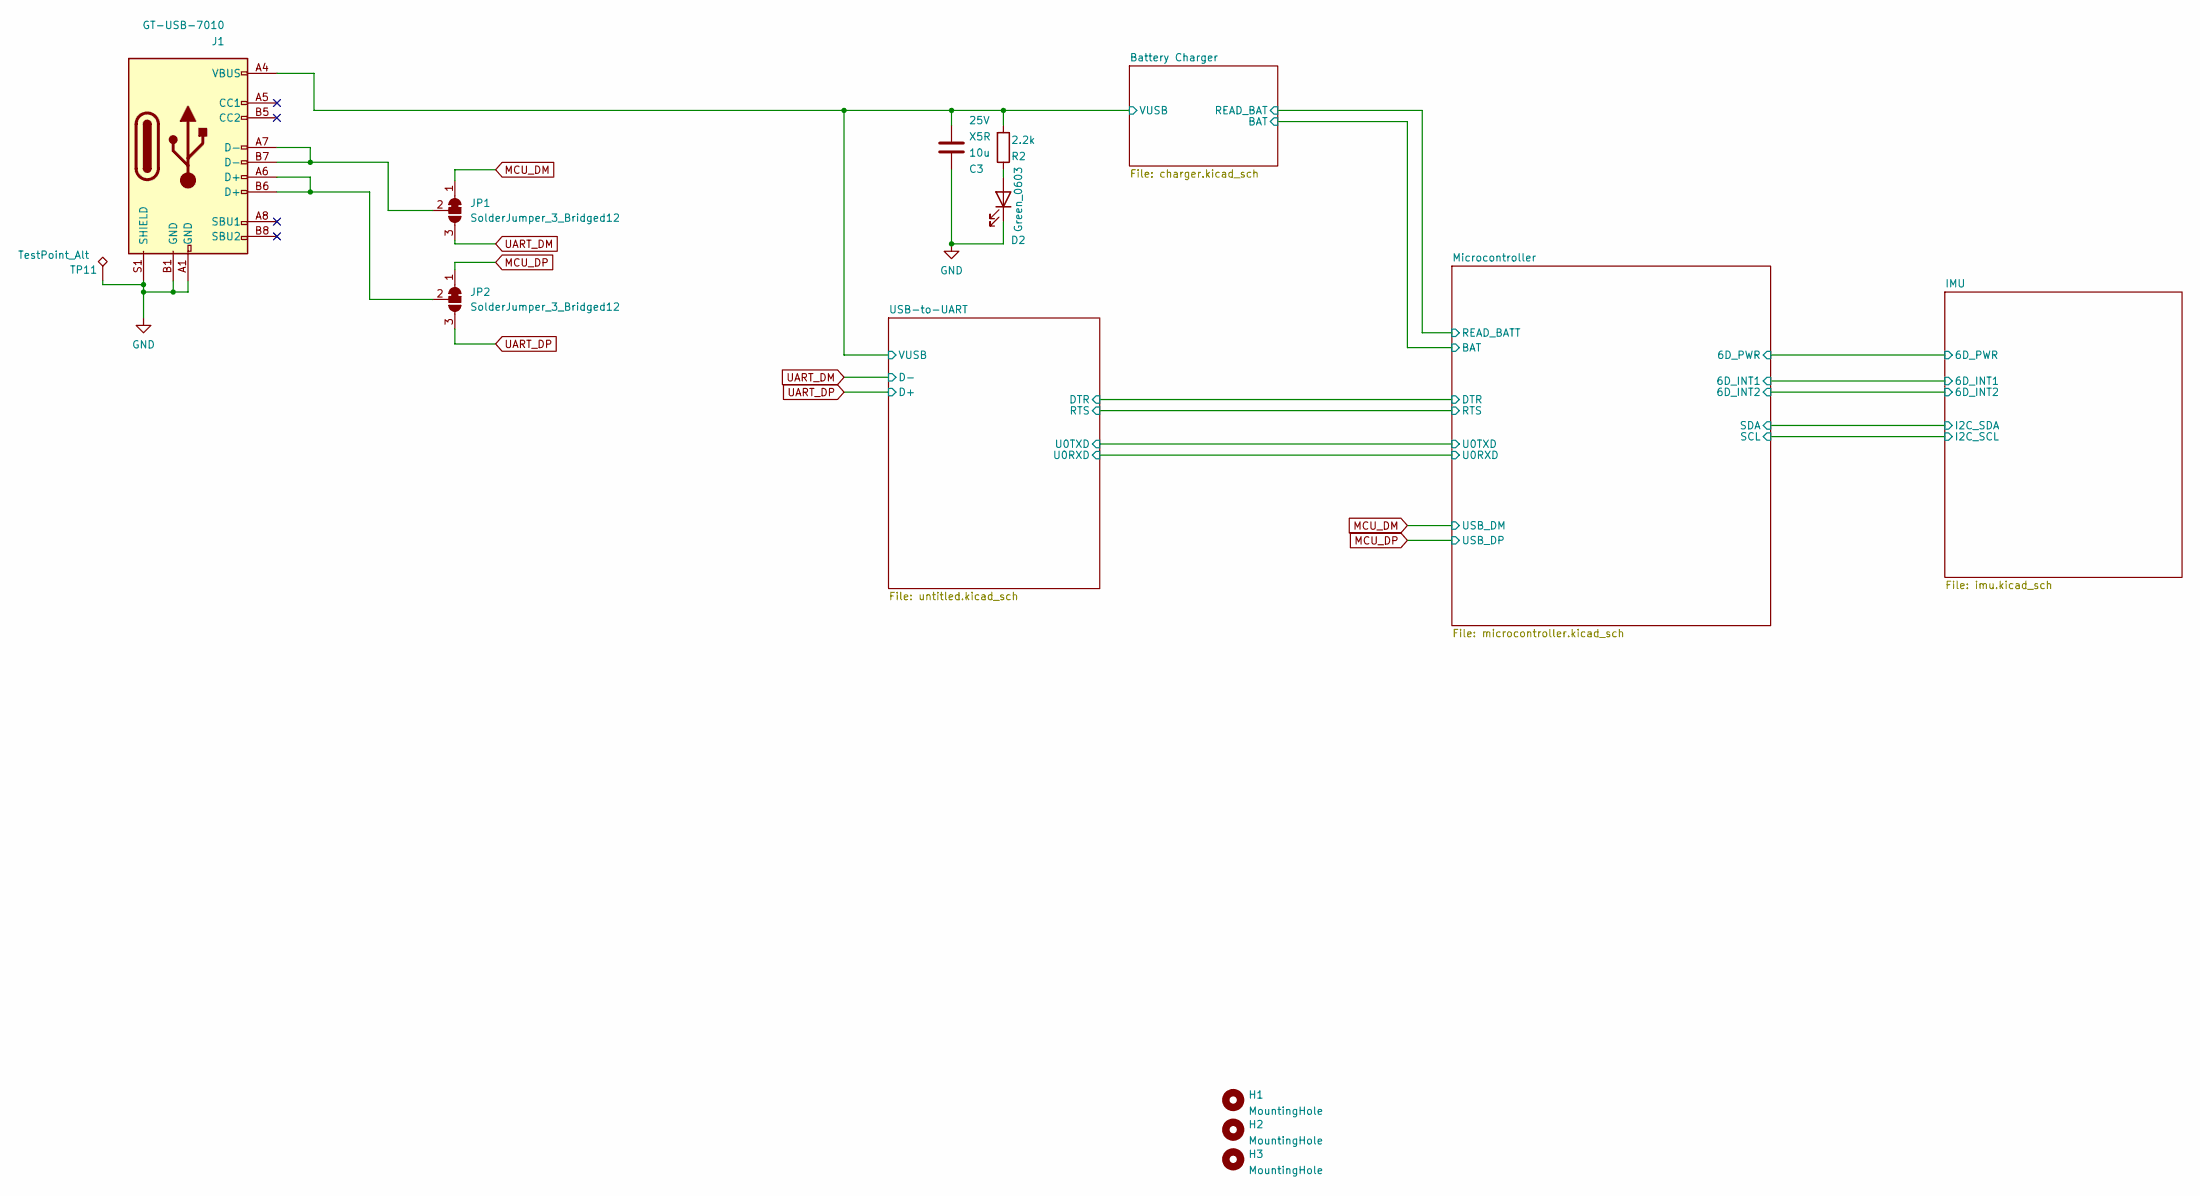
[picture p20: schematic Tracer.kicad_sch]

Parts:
C3: 10u; C_0805_2012Metric; Voltage 25V; LCSC C15850
D2: Green_0603; LED_0603_1608Metric; LCSC C72043
H1, H2, H3: MountingHole; MountingHole_2.2mm_M2_Small
J1: GT-USB-7010; GT-USB-7010A; LCSC C963370
JP1, JP2: SolderJumper_3_Bridged12; SolderJumper-3_P1.3mm_Bridged12_Pad1.0x1.5mm_NumberLabels
R2: 2.2k; R_0402_1005Metric; LCSC C25879
TP11: TestPoint_Alt; TestPoint_Pad_1.0x1.0mm

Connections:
/Battery Charger/VUSB: C3.2, J1.A4 (VBUS), J1.A9 (VBUS), J1.B4 (VBUS), J1.B9 (VBUS), R2.2; also elsewhere on the board
GND: C3.1, D2.1 (K), J1.A1 (GND), J1.B1 (GND), J1.S1 (SHIELD), TP11.1; also elsewhere on the board
MCU_DM: JP1.1 (A); also elsewhere on the board
MCU_DP: JP2.1 (A); also elsewhere on the board
unnamed: D2.2 (A), R2.1
unnamed: J1.A7 (D-), J1.B7 (D-), JP1.2 (C)
unnamed: J1.A6 (D+), J1.B6 (D+), JP2.2 (C)
UART_DM: JP1.3 (B); also elsewhere on the board
UART_DP: JP2.3 (B); also elsewhere on the board

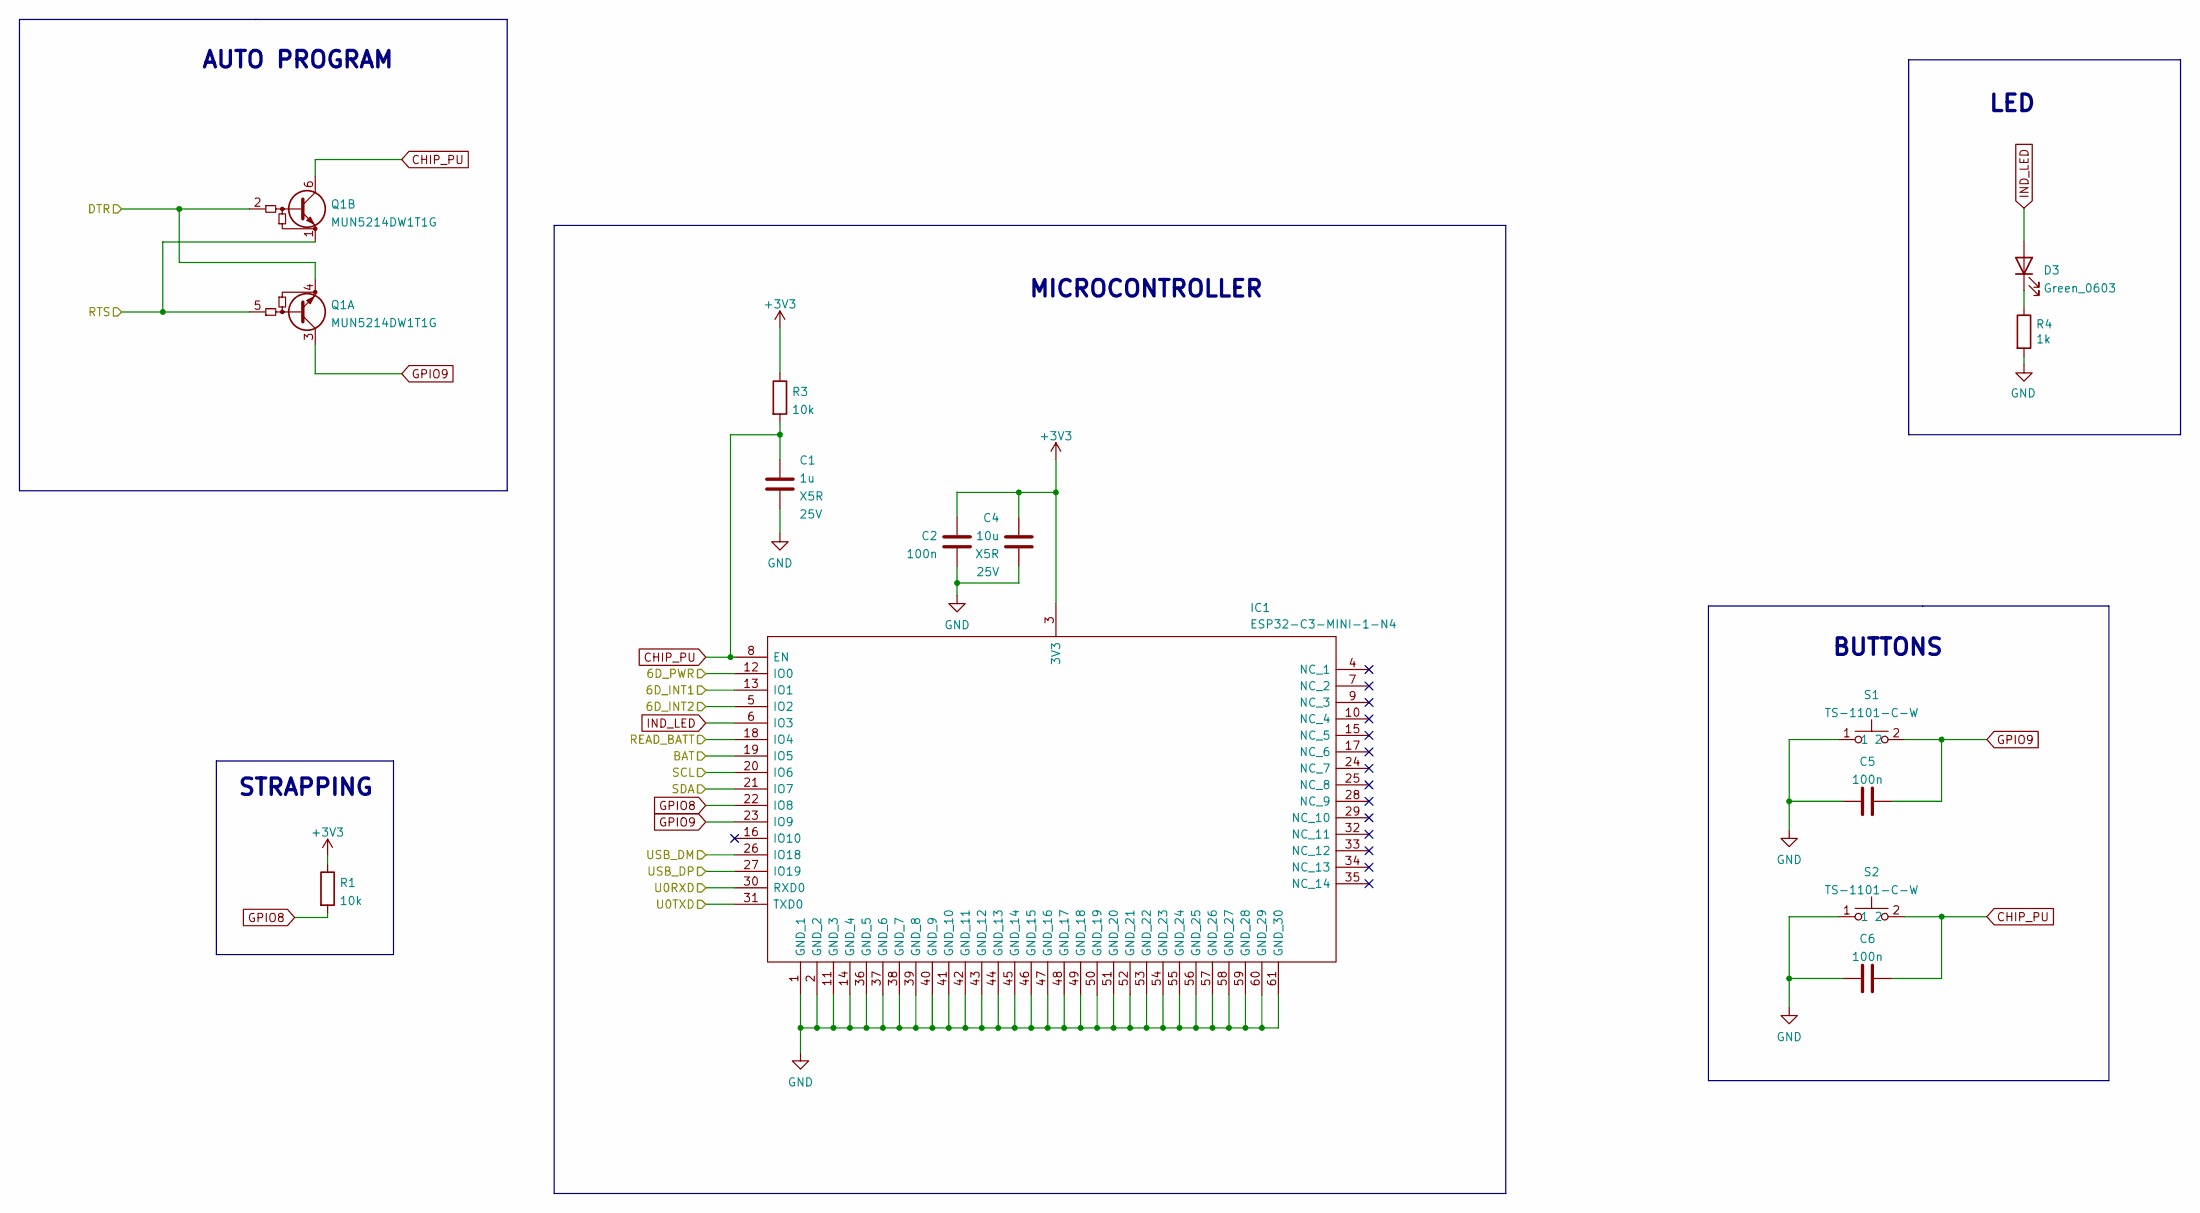
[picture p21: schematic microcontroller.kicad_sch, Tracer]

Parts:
C1: 1u; C_0402_1005Metric; Voltage 25V; LCSC C52923
C2, C5, C6: 100n; C_0402_1005Metric; LCSC C307331
C4: 10u; C_0805_2012Metric; Voltage 25V; LCSC C15850
D3: Green_0603; LED_0603_1608Metric; LCSC C72043
IC1: ESP32-C3-MINI-1-N4; ESP32C3MINI1N4; Manufacturer_Part_Number ESP32-C3-MINI-1-N4; Mouser Part Number 356-ESP32-C3-MINI1N4
Q1: MUN5214DW1T1G; SOT-363_SC-70-6; LCSC C94403
R1, R3: 10k; R_0402_1005Metric; LCSC C25744
R4: 1k; R_0402_1005Metric; LCSC C11702
S1, S2: TS-1101-C-W; TS1101CW; Manufacturer_Part_Number TS-1101-C-W; LCSC C318938

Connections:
+3V3: C2.1, C4.1, IC1.3 (3V3), R1.1, R3.1; also elsewhere on the board
/Battery Charger/BAT: IC1.19 (IO5); also elsewhere on the board
/Battery Charger/READ_BAT: IC1.18 (IO4); also elsewhere on the board
/IMU/6D_INT1: IC1.13 (IO1); also elsewhere on the board
/IMU/6D_INT2: IC1.5 (IO2); also elsewhere on the board
/IMU/6D_PWR: IC1.12 (IO0); also elsewhere on the board
/IMU/I2C_SCL: IC1.20 (IO6); also elsewhere on the board
/IMU/I2C_SDA: IC1.21 (IO7); also elsewhere on the board
/Microcontroller/DTR: Q1.2 (B2), Q1.4 (E1); also elsewhere on the board
/Microcontroller/RTS: Q1.1 (E2), Q1.5 (B1); also elsewhere on the board
/Microcontroller/U0RXD: IC1.30 (RXD0); also elsewhere on the board
/Microcontroller/U0TXD: IC1.31 (TXD0); also elsewhere on the board
CHIP_PU: C1.1, C6.2, IC1.8 (EN), Q1.6 (C2), R3.2, S2.2
GND: C1.2, C2.2, C4.2, C5.1, C6.1, IC1.1 (GND_1), IC1.2 (GND_2), IC1.11 (GND_3), IC1.14 (GND_4), IC1.36 (GND_5), IC1.37 (GND_6), IC1.38 (GND_7), IC1.39 (GND_8), IC1.40 (GND_9), IC1.41 (GND_10), IC1.42 (GND_11), IC1.43 (GND_12), IC1.44 (GND_13), IC1.45 (GND_14), IC1.46 (GND_15), IC1.47 (GND_16), IC1.48 (GND_17), IC1.49 (GND_18), IC1.50 (GND_19), IC1.51 (GND_20), IC1.52 (GND_21), IC1.53 (GND_22), IC1.54 (GND_23), IC1.55 (GND_24), IC1.56 (GND_25), IC1.57 (GND_26), IC1.58 (GND_27), IC1.59 (GND_28), IC1.60 (GND_29), IC1.61 (GND_30), R4.2, S1.1, S2.1; also elsewhere on the board
GPIO8: IC1.22 (IO8), R1.2
GPIO9: C5.2, IC1.23 (IO9), Q1.3 (C1), S1.2
IND_LED: D3.2 (A), IC1.6 (IO3)
MCU_DM: IC1.26 (IO18); also elsewhere on the board
MCU_DP: IC1.27 (IO19); also elsewhere on the board
unnamed: D3.1 (K), R4.1

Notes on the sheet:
MICROCONTROLLER
LED
AUTO PROGRAM
BUTTONS
STRAPPING

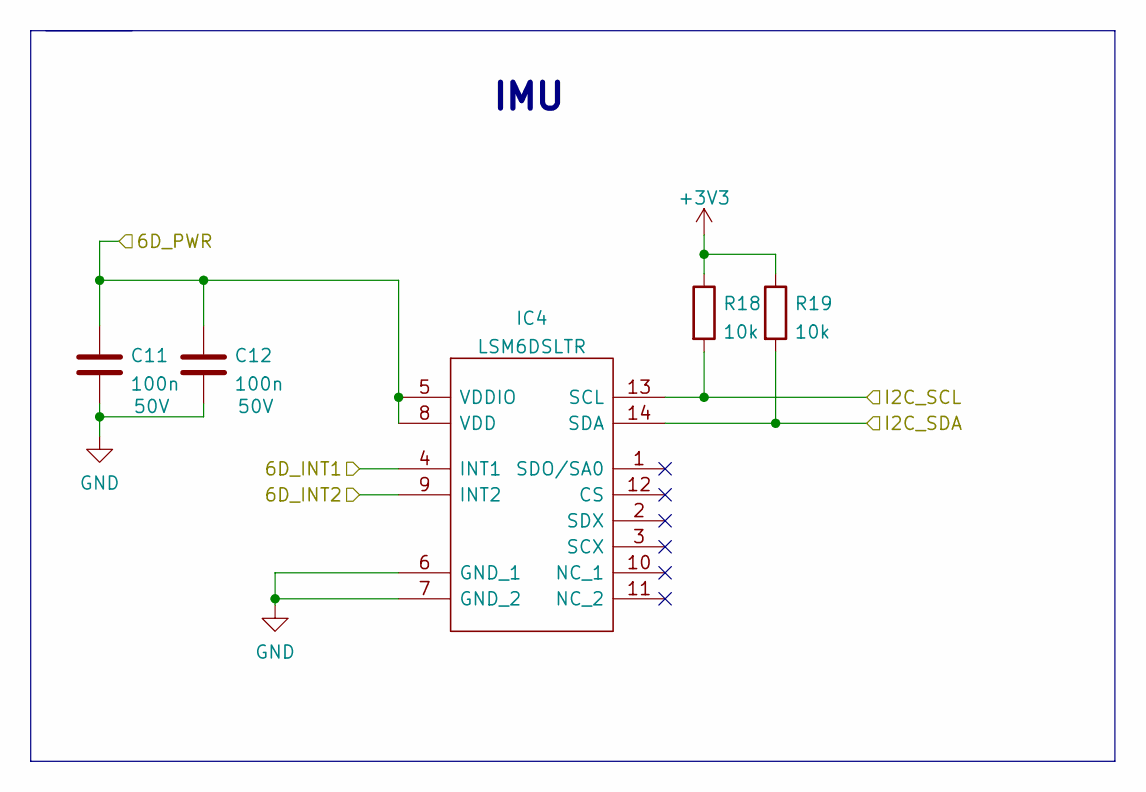
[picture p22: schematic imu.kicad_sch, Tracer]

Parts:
C11, C12: 100n; C_0402_1005Metric; Voltage 50V; LCSC C307331
IC4: LSM6DSLTR; Manufacturer_Part_Number LSM6DSLTR; Mouser Part Number 511-LSM6DSLTR
R18, R19: 10k; R_0402_1005Metric; LCSC C25744

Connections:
+3V3: R18.1, R19.1; also elsewhere on the board
/IMU/6D_INT1: IC4.4 (INT1); also elsewhere on the board
/IMU/6D_INT2: IC4.9 (INT2); also elsewhere on the board
/IMU/6D_PWR: C11.1, C12.1, IC4.5 (VDDIO), IC4.8 (VDD); also elsewhere on the board
/IMU/I2C_SCL: IC4.13 (SCL), R18.2; also elsewhere on the board
/IMU/I2C_SDA: IC4.14 (SDA), R19.2; also elsewhere on the board
GND: C11.2, C12.2, IC4.6 (GND_1), IC4.7 (GND_2); also elsewhere on the board

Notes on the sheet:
IMU

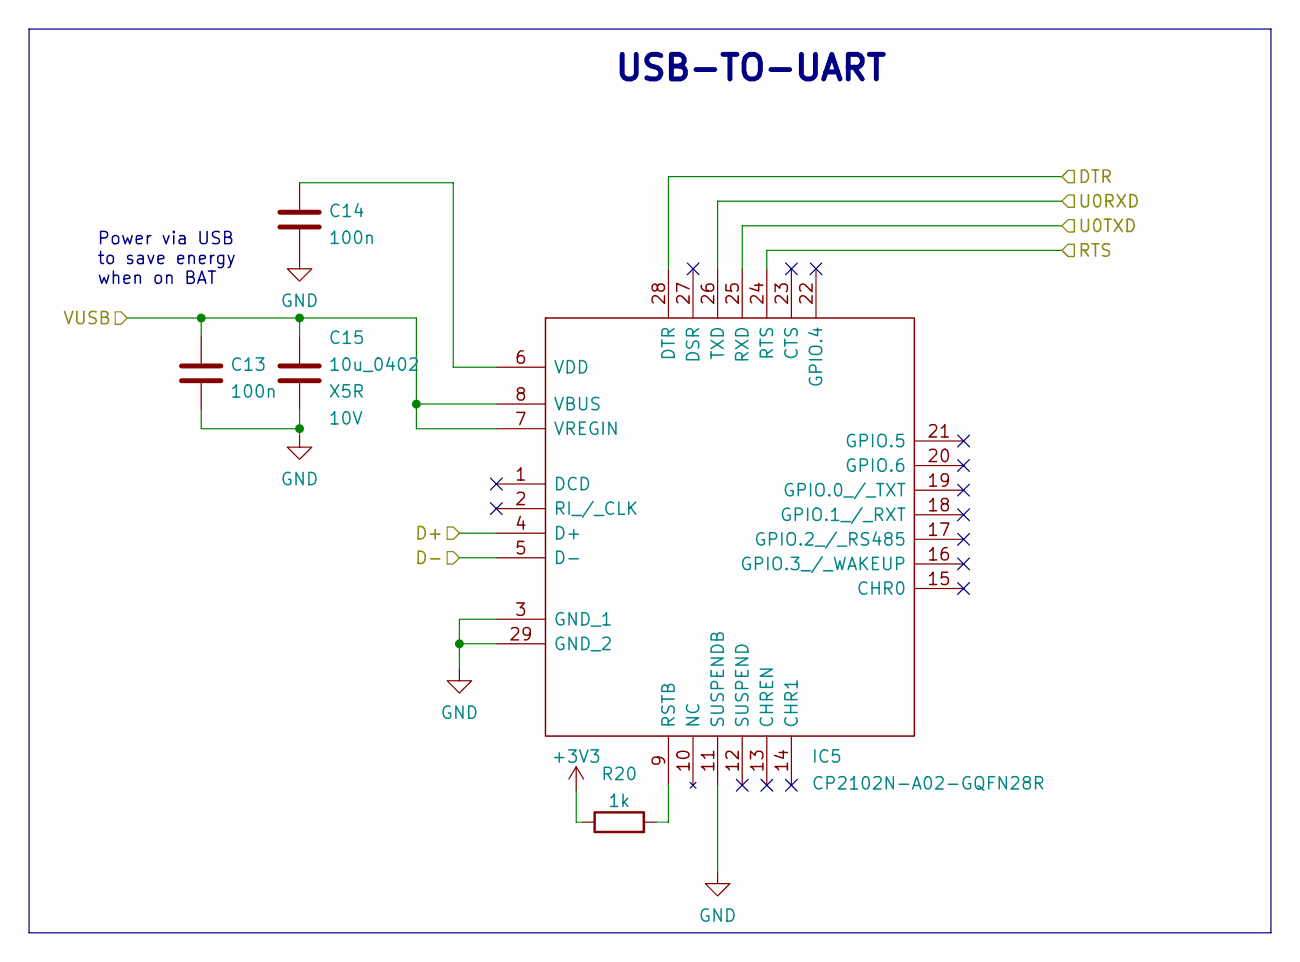
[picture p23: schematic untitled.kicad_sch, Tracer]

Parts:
C13, C14: 100n; C_0402_1005Metric; LCSC C307331
C15: 10u_0402; C_0402_1005Metric; Voltage 10V; LCSC C315248
IC5: CP2102N-A02-GQFN28R; QFN50P500X500X80-29N-D; Manufacturer_Part_Number CP2102N-A02-GQFN28R; Mouser Part Number 634-CP2102NA02QFN28R
R20: 1k; R_0402_1005Metric; LCSC C11702

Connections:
+3V3: R20.1; also elsewhere on the board
/Battery Charger/VUSB: C13.1, C15.1, IC5.7 (VREGIN), IC5.8 (VBUS); also elsewhere on the board
/Microcontroller/DTR: IC5.28 (DTR); also elsewhere on the board
/Microcontroller/RTS: IC5.24 (RTS); also elsewhere on the board
/Microcontroller/U0RXD: IC5.26 (TXD); also elsewhere on the board
/Microcontroller/U0TXD: IC5.25 (RXD); also elsewhere on the board
GND: C13.2, C14.2, C15.2, IC5.3 (GND_1), IC5.11 (SUSPENDB), IC5.29 (GND_2); also elsewhere on the board
unnamed: IC5.9 (RSTB), R20.2
unnamed: C14.1, IC5.6 (VDD)
UART_DM: IC5.5 (D-); also elsewhere on the board
UART_DP: IC5.4 (D+); also elsewhere on the board

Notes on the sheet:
USB-TO-UART
Power via USB to save energy when on BAT

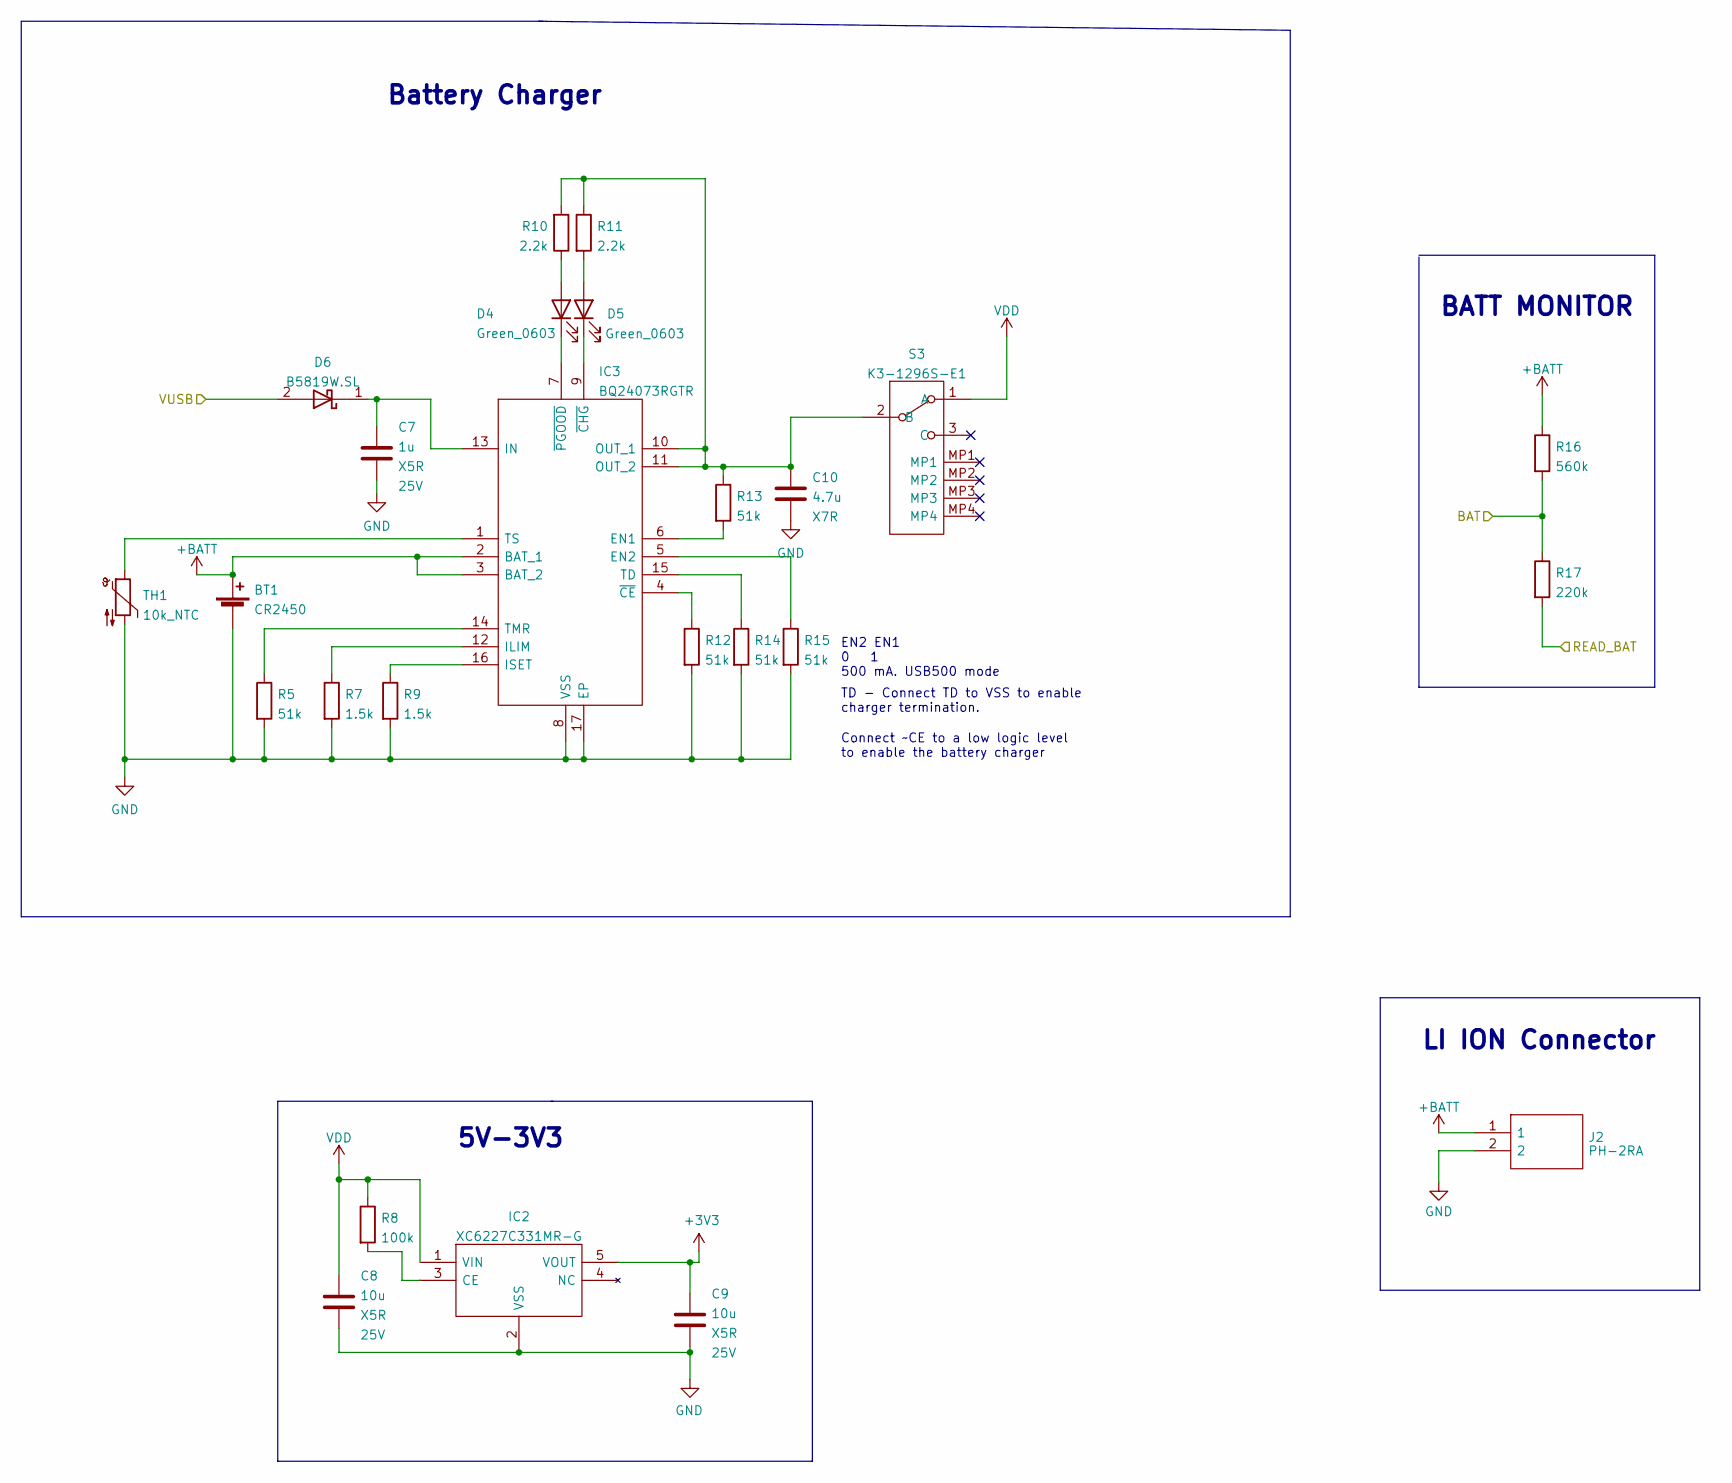
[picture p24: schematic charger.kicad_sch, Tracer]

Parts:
BT1: CR2450; BS-24-B4AK014; LCSC C964813
C7: 1u; C_0402_1005Metric; Voltage 25V; LCSC C52923
C8, C9: 10u; C_0805_2012Metric; Voltage 25V; LCSC C15850
C10: 4.7u; C_1206_3216Metric; Rating 50V; LCSC C29823
D4, D5: Green_0603; LED_0603_1608Metric; LCSC C72043
D6: B5819W.SL; B5819WSL; Manufacturer_Part_Number B5819W.SL; LCSC C8598
IC2: XC6227C331MR-G; SOT95P280X130-5N; Manufacturer_Part_Number XC6227C331MR-G; Mouser Part Number 865-XC6227C331MR-G
IC3: BQ24073RGTR; QFN50P300X300X100-17N-D; Manufacturer_Part_Number BQ24073RGTR; Mouser Part Number 595-BQ24073RGTR
J2: PH-2RA; SHDRRA2W50P0X200_1X2_600X760X510P; Manufacturer_Part_Number A2001WR-2P Thru-hole; Mouser Part Number 763-A2001WR2P
R5, R12, R13, R14, R15: 51k; R_0402_1005Metric; LCSC C25794
R7, R9: 1.5k; R_0402_1005Metric; LCSC C25867
R8: 100k; R_0402_1005Metric; LCSC C25741
R10, R11: 2.2k; R_0402_1005Metric; LCSC C25879
R16: 560k; R_0603_1608Metric; LCSC C23203
R17: 220k; R_0402_1005Metric; LCSC C25767
S3: K3-1296S-E1; K31296SE1; Manufacturer_Part_Number K3-1296S-E1; LCSC C128955
TH1: 10k_NTC; R_0402_1005Metric; MPN NCU15XH103F6SRC; LCSC C333993

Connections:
+3V3: C9.1, IC2.5 (VOUT); also elsewhere on the board
+BATT: BT1.1 (+), IC3.2 (BAT_1), IC3.3 (BAT_2), J2.1, R16.1
/Battery Charger/BAT: R16.2, R17.1; also elsewhere on the board
/Battery Charger/READ_BAT: R17.2; also elsewhere on the board
/Battery Charger/VUSB: D6.2; also elsewhere on the board
GND: BT1.2 (-), C7.2, C8.2, C9.2, C10.2, IC2.2 (VSS), IC3.8 (VSS), IC3.17 (EP), J2.2, R5.2, R7.2, R9.2, R12.2, R14.2, R15.2, TH1.2; also elsewhere on the board
unnamed: D4.2 (A), R10.1
unnamed: D4.1 (K), IC3.7 (~PGOOD)
unnamed: D5.2 (A), R11.2
unnamed: D5.1 (K), IC3.9 (~CHG)
unnamed: IC2.3 (CE), R8.2
unnamed: IC3.6 (EN1), R13.2
unnamed: IC3.5 (EN2), R15.1
unnamed: IC3.12 (ILIM), R7.1
unnamed: C7.1, D6.1, IC3.13 (IN)
unnamed: IC3.16 (ISET), R9.1
unnamed: C10.1, IC3.10 (OUT_1), IC3.11 (OUT_2), R10.2, R11.1, R13.1, S3.2 (B)
unnamed: IC3.15 (TD), R14.1
unnamed: IC3.14 (TMR), R5.1
unnamed: IC3.1 (TS), TH1.1
unnamed: IC3.4 (~CE), R12.1
VDD: C8.1, IC2.1 (VIN), R8.1, S3.1 (A)

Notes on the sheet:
TD - Connect TD to VSS to enable charger termination.
5V-3V3
EN2 EN1 0 1 500 mA. USB500 mode
LI ION Connector
Connect ~CE to a low logic level to enable the battery charger
BATT MONITOR
Battery Charger

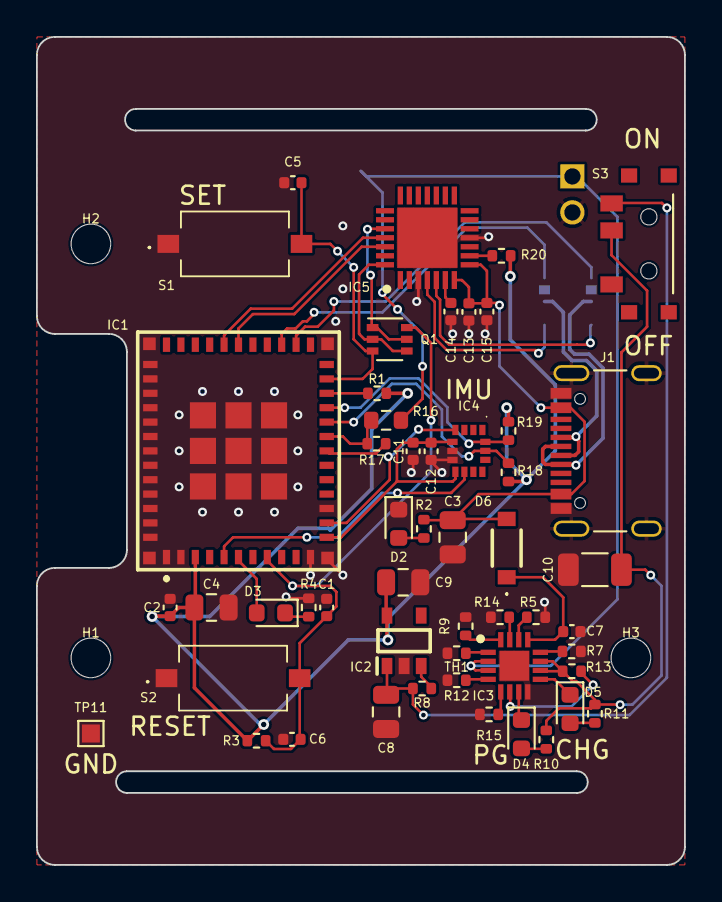
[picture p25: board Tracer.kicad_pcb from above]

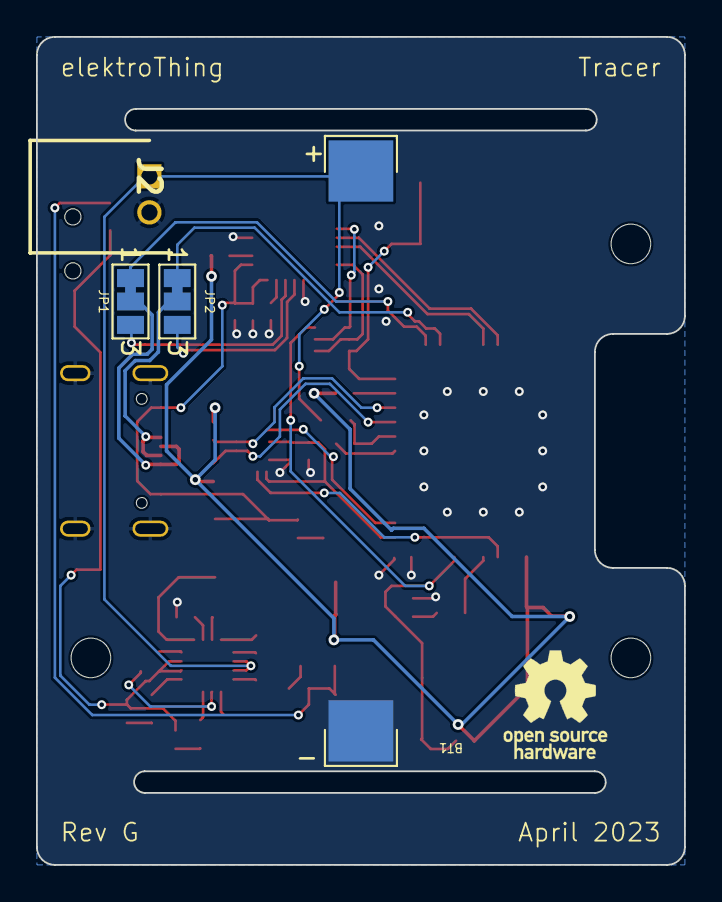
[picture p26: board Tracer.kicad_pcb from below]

Board: 4 copper layers, 36.0 x 46.0 mm, 58 parts (4 on the bottom side), 45 nets.

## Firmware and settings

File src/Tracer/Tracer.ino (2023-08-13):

#include "application.h"

RTC_NOINIT_ATTR unsigned int state = 0;

#define   PRINT_IMU   1

Application app;

void setup() 
{
  // put your setup code here, to run once:
  Serial.begin(115200);

  app.init(state, 100);
  Serial.println("Processor came out of reset.\n");
}


void loop()
{
  // This loop must not have any delays.
  if (digitalRead(SET) == 0)
  {
    state++;
    if(state>3)
    {
      state = 0;
    }
    delay(500);
    ESP.restart();
  };

  app.update(state);
  app.sampleIMU();
}

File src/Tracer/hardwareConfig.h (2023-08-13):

#define   IMU_PWR     0
#define   IMU_INT1    1
#define   I2C_SCL     6
#define   I2C_SDA     7
#define   DEBUG_LED   3
#define   SET         9

#define   BATT        5
#define   READ_BATT   4

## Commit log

2022-06-08 updated code and schematic
2023-08-13 Updated with latest rev
    [bom.csv, designators.csv, positions.csv]
2024-05-18 Migrating to public repo
    [Matching.kicad_sch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]
